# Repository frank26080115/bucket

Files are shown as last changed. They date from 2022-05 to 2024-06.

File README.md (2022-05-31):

Bucket
======

This is a tool made to transfer and backup photos from a professional camera while in-the-field. Built with a Raspberry Pi 4 (other Pis will work too, it's all just Python code), using Wi-Fi for file transfers and USB disks for file storage, powered by batteries.

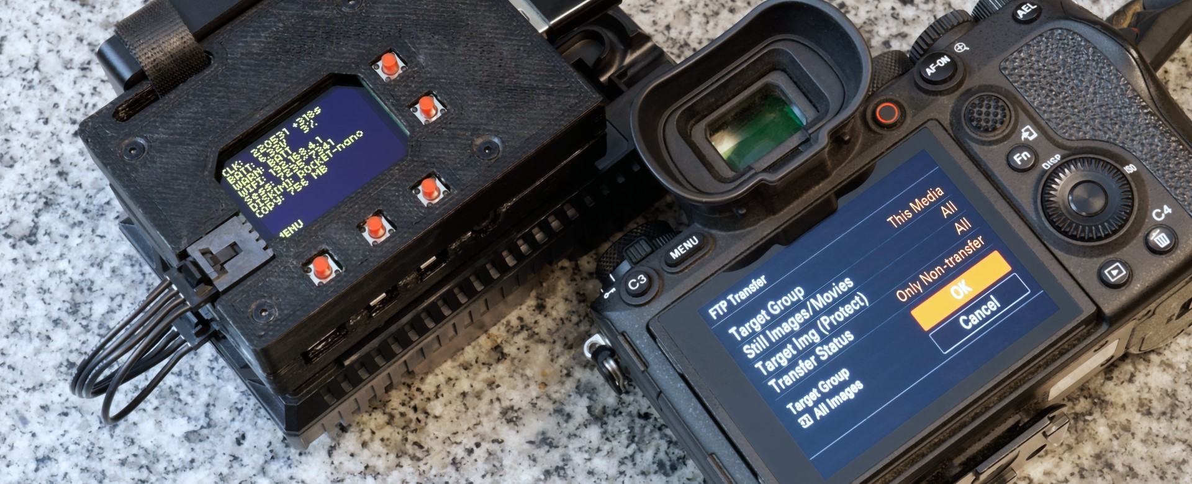
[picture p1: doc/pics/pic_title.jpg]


The Problem
----

 While on photography trips, I'm running out of storage on my camera's memory cards. They are expensive memory cards and I can't buy too many of them ($400 for 160 GB, and the camera needs two). I don't want to go back to a hotel before clearing out a memory card either.

So the strategy is to wirelessly transfer the files into a cheaper-slower-but-bigger storage device (TB sized USB disks) simultaneously as the camera is shooting. The slower speed should be fine because the transfers will happen during the down-time, when I'm walking around not taking pictures. USB disks at this size typically cost just a bit over $100 (genuine, authentic, non-scam ones) and require USB-3.0 ports.

Once the photos are in the bigger storage device, I can clear the expensive-and-smaller memory cards without going back to a hotel, using in-camera quick-reformat.

This project needs to be done by late June of 2022, my next vacation. (I hope this explains some very weird decisions I've made)

Features
----

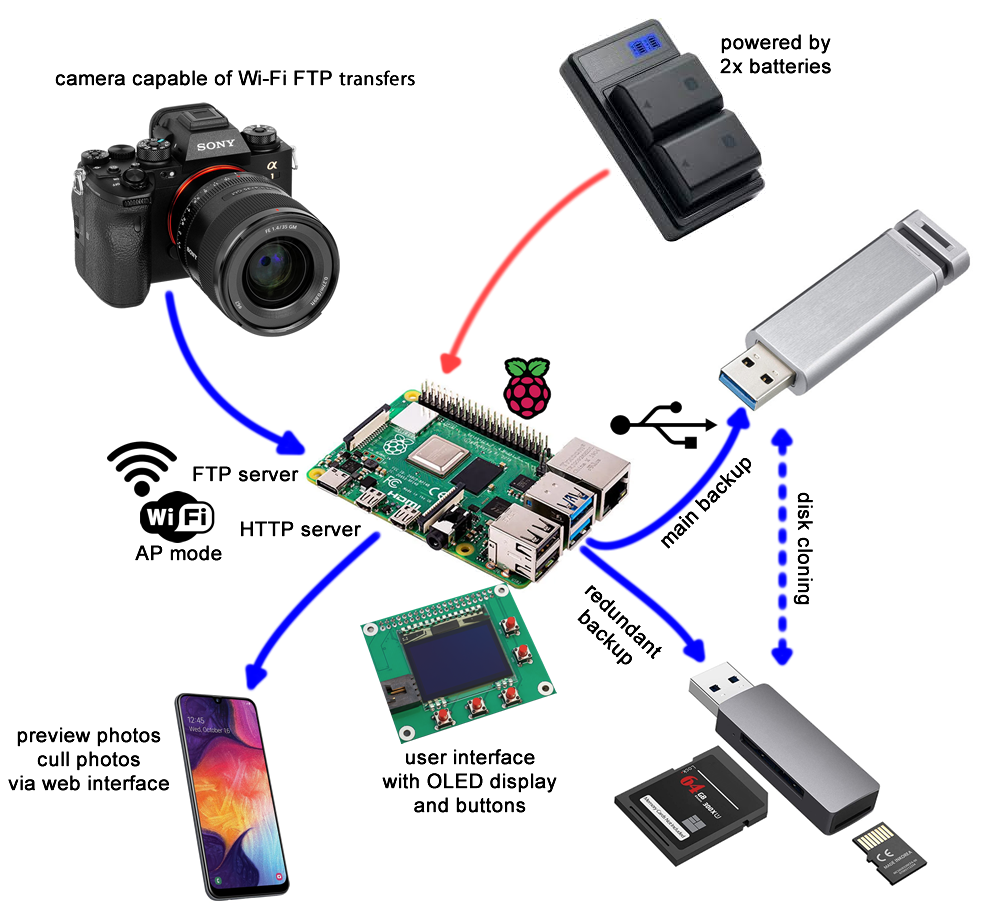
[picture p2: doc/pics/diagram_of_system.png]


Runs as a FTP server for professional cameras to transfer photos into. A redundant copy of the photo is made if 2 USB disks are inserted. (most professional cameras have two card slots for the purpose of having redundancy as well)

Copies photos from SD card if a SD card reader is inserted into a USB port. Or plug in the camera itself (configure it to run in mass storage mode, and disable USB charging).

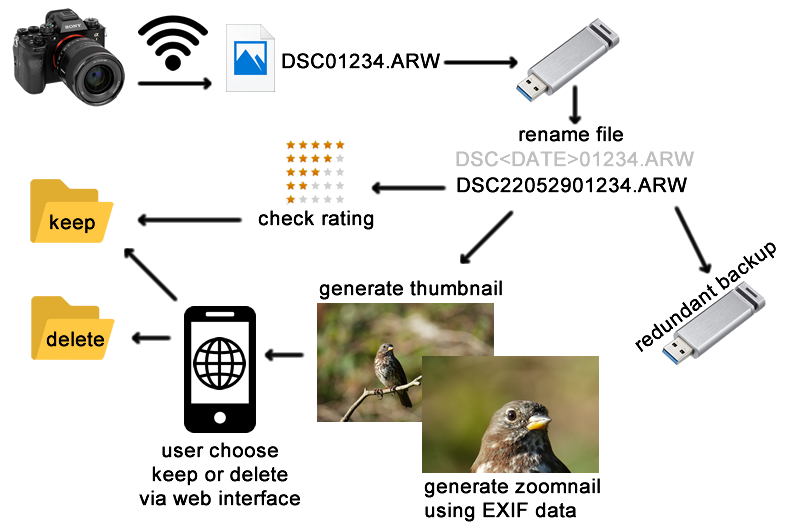
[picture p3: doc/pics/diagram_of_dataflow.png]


The file-names for the photos are typically numbered from 0 to 9999. This isn't a lot of photos and rolls over quickly. When a photo is copied, it is automatically renamed with a much longer number that indicates the date it was taken. The date makes every photo file-name unique and can be easily searched-for and sorted.

EXIF data of the photo is checked for the photo's 5-star rating, if it is rated in-camera, then it is automatically marked for keeping.

Performs disk-cloning when multiple USB disks are inserted.

Uses a HTTP server to show an image gallery in a web browser. The user can choose to keep or delete a photo from the web-page. Each photo is checked for where the camera focused on, and a zoomed-in cropped thumbnail is shown to the user showing where the camera focused (which is even cooler since my camera have AI driven bird-eye-detect).

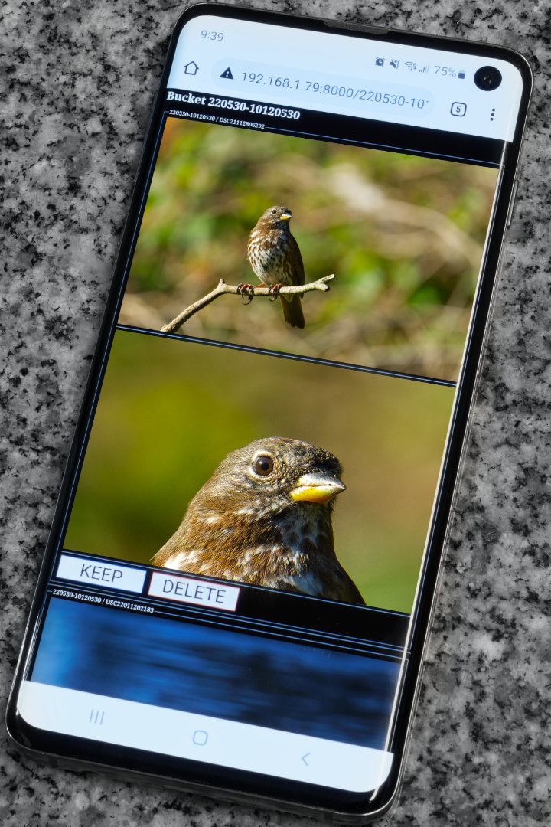
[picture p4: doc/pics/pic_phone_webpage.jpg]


This allows for a very quick decision whether or not an image is in-focus enough to keep. This implementation keeps the file-sizes small for the web-page, but the user can still click into the full resolution file too.

The software keeps track of the numbers in the file-names. If the number sequence skips a number, it might mean a missing photo, the missing number is shown to the user so they can check in the camera what happened. The camera can indicate a failed FTP transfer, but usually it just retries until it works. This is only useful when the camera is setup to transfer-as-you-shoot.

Hardware UX
----

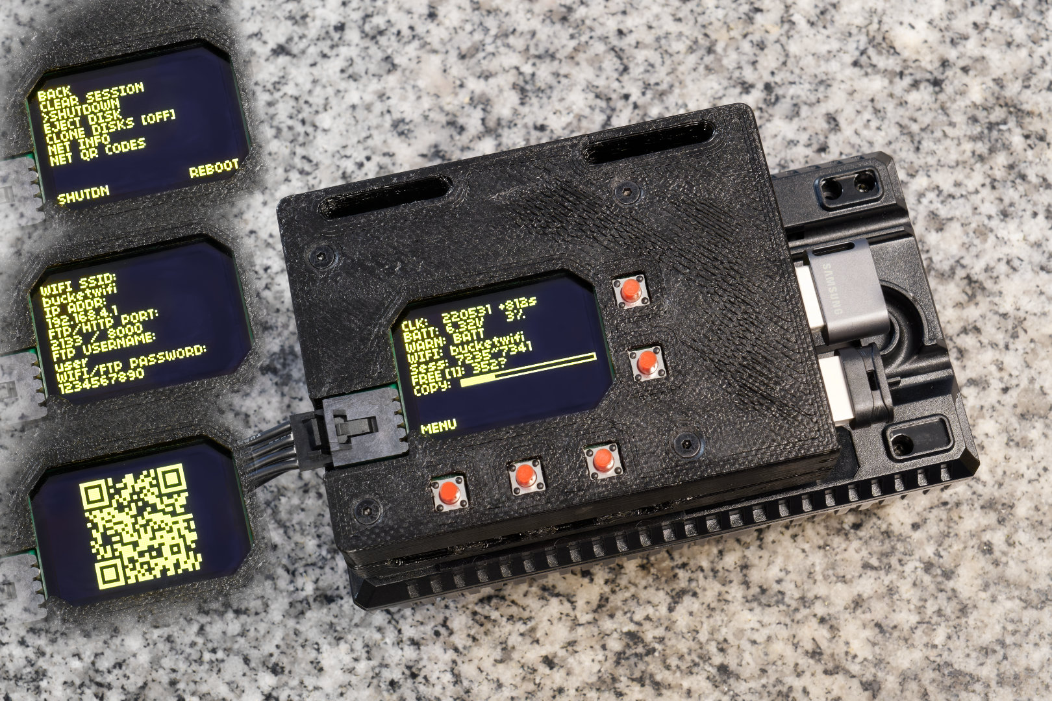
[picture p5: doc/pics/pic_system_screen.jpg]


The UI involves a 102x64 OLED screen and 5 buttons. It is very readable in all lighting conditions. The 5 buttons are divided into 2 up/down buttons and 3 action buttons.

The screen shows the most important information, such as the time (which is kind of like a heart-beat), the number of photos transferred, the amount of disk space remaining, etc.

There is a menu that can be accessed, the menu items are navigated with the up/down buttons. From the menu, the user can do things like initiate drive-cloning.

From the menu, the user can quickly check the Wi-Fi AP's credentials, the FTP IP address, and FTP credentials. It can also display the Wi-Fi credentials and HTTP URL as QR codes.

There is a buzzer that buzzes when there's a problem that requires the user's immediate attention, such as a disk running out of space, or if the battery is too low, etc. The user can press a button to acknowledge the problem to turn off the buzzer.

Hat Circuit and 3D Printed Box
----

This is the circuit I designed to go on top of the Raspberry Pi.

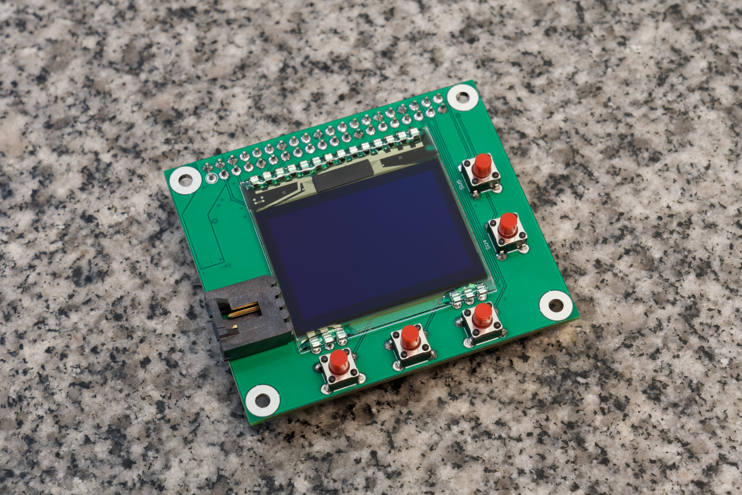
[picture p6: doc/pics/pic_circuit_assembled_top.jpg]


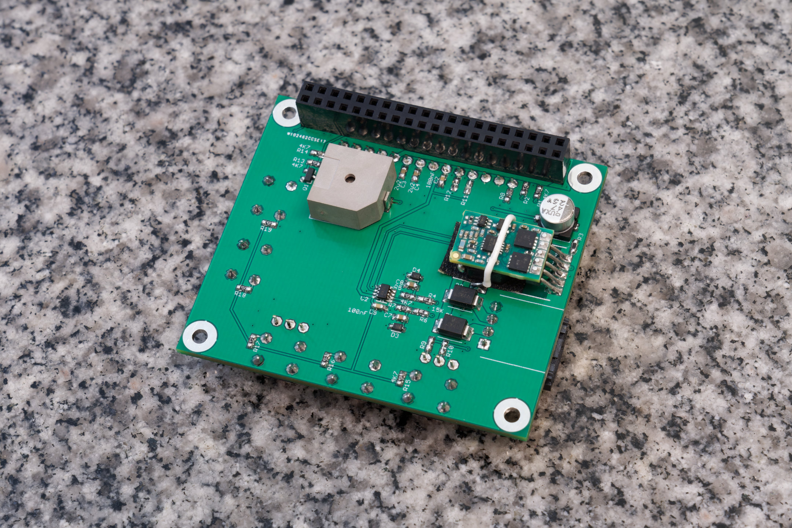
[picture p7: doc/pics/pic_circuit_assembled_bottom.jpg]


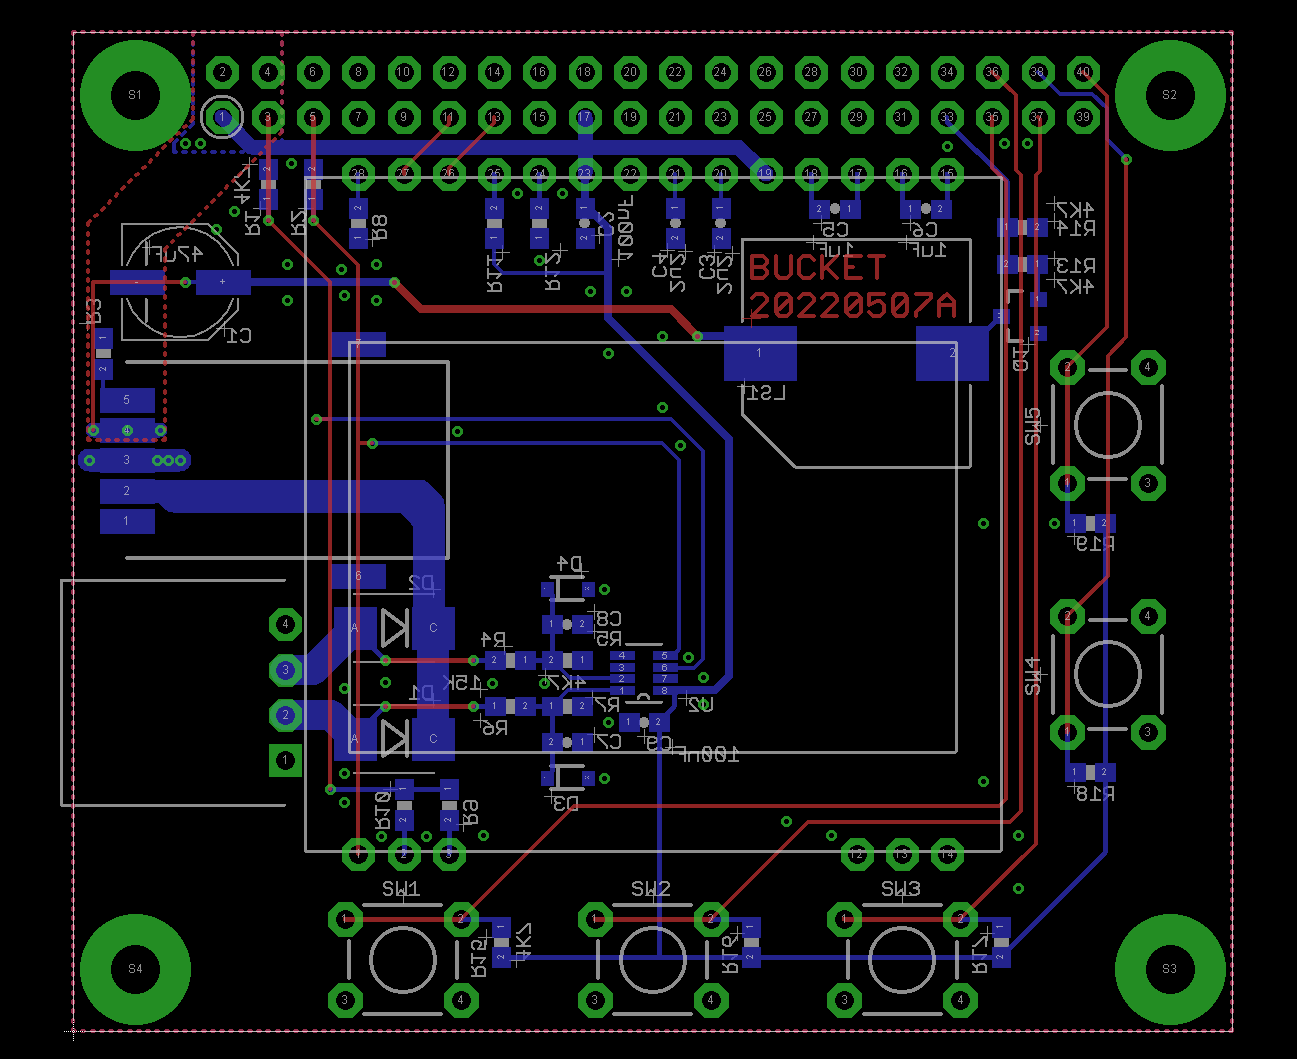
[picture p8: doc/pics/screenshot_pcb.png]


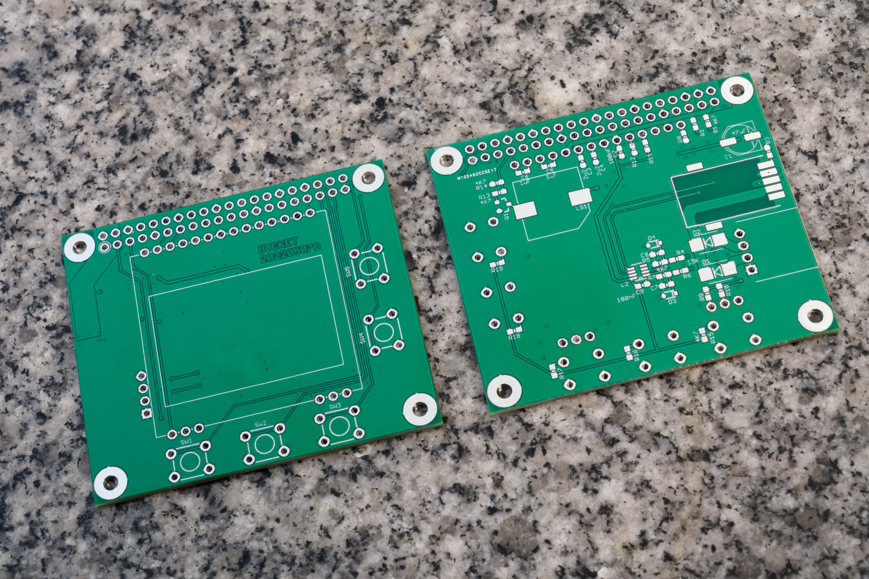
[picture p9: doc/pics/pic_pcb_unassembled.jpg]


A 3D printed box is designed to protect the entire assembly. It is 3D printed in PETG plastic, because this whole thing gets super hot while running, PLA plastic just won't handle it.

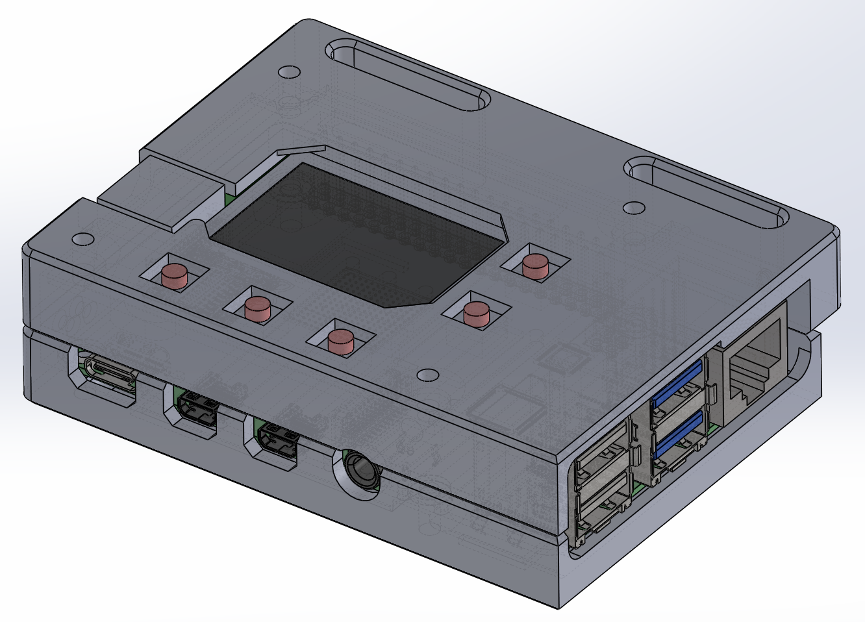
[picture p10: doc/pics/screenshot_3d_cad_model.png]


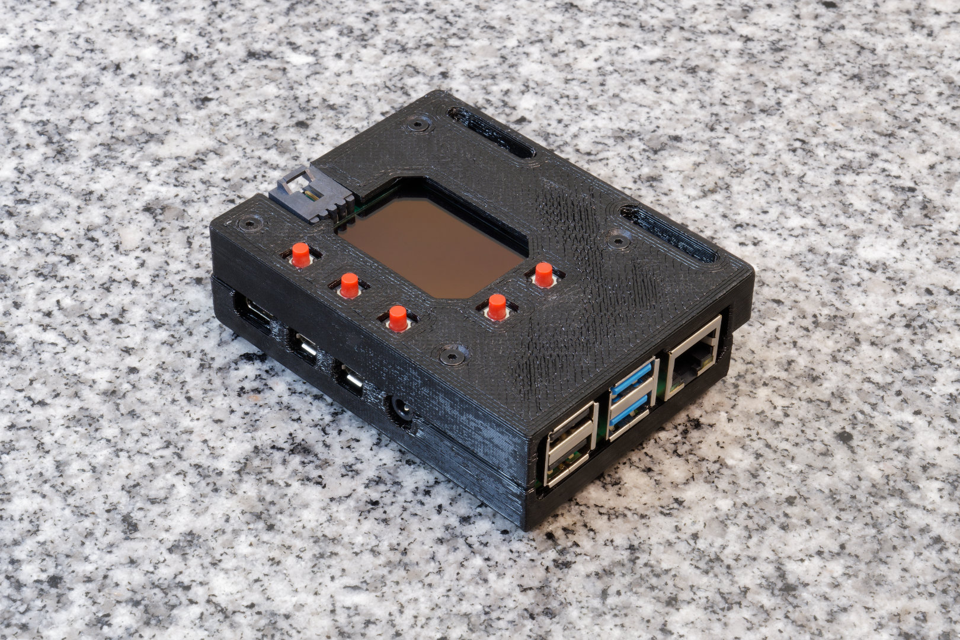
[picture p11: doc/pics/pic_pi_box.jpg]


The slots in the design are meant for strapping down a small USB SSD. These SSDs can have one or two TB of storage and should be pretty reliable since they use M.2 drives inside.

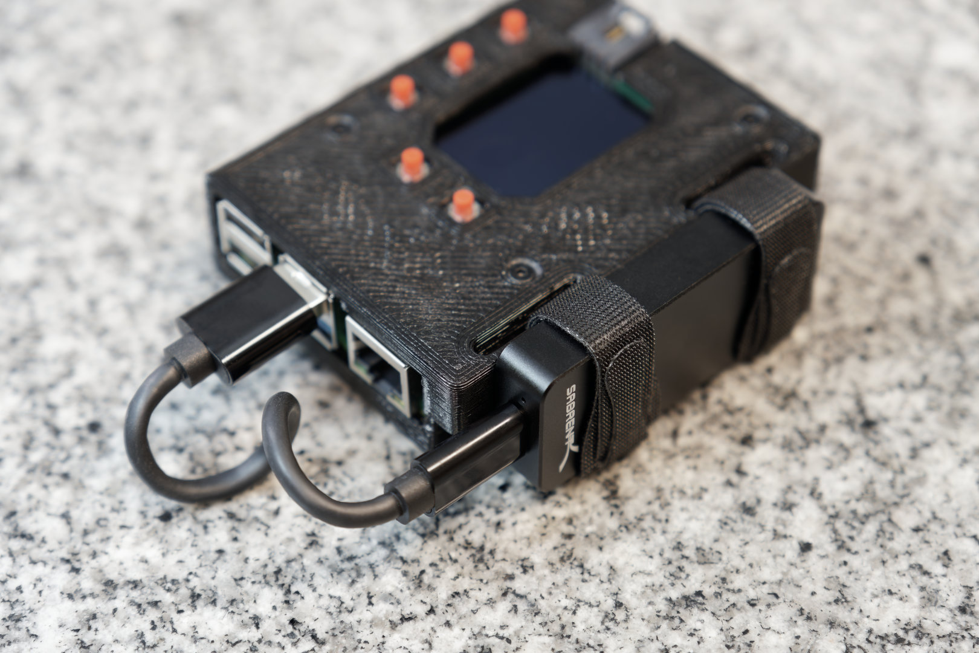
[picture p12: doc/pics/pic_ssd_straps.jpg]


Software Architecture
----

This is just one massive Python project, spread across several modules. The hardware IO, various servers, and the main application, can all be independently tested. In fact, because Python is very cross-platform, I did most of my testing on Windows with a simulated screen.

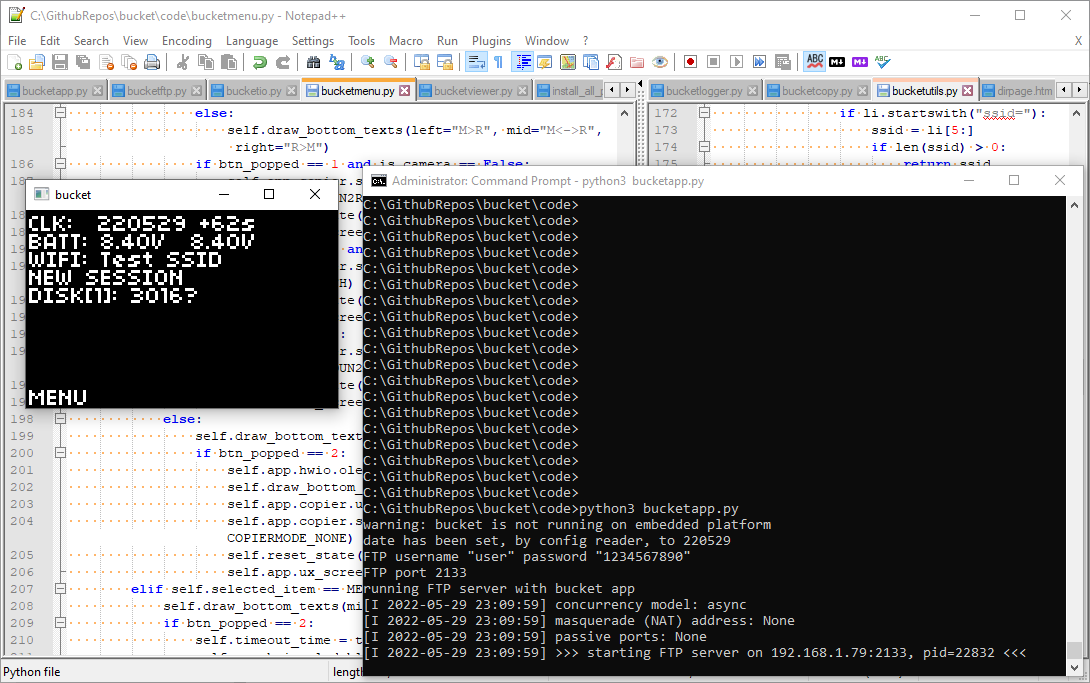
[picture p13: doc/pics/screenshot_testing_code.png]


The intention is to improve the reliability of this project by making the Raspberry Pi's microSD card read-only. The Python script will scan all mounted disks for a config file when it starts. This way, the user can still specify some parameters without ever writing to the microSD card.

The Python script will also log events and errors to the first available mounted disk.

The Python script is called upon by `/etc/rc.local`.

The library I used for the FTP server is [pyftpdlib](https://pypi.org/project/pyftpdlib/). The server class can be inherited, callback functions can be added, and a lot of the pathing functions had to be overridden.

The UI used a combination of [CircuitPython](https://circuitpython.org/) (and including the adafruit-circuitpython-ssd1306 library), [gpiozero](https://gpiozero.readthedocs.io/), and [Pillow](https://pillow.readthedocs.io/)

The HTTP server used Python's [built-in HTTP server library](https://docs.python.org/3/library/http.server.html). The HTML pages contains some [JQuery](https://jquery.com/) and uses lazy-loading images.

The EXIF related functions I borrowed [ExifTool](https://exiftool.org/), it's a Perl project but I call upon it as a subprocess from within Python.

USB disk auto-mounting is handled by [the usbmount Debian package](https://github.com/rbrito/usbmount/).

Threads
----

This device packs a bunch of features that involve IO against USB drives, and some of those tasks are more important. The software running has many threads that have multiple task queues with varying priorities.

The main thread is the GUI thread, which runs once every 0.2 seconds, giving a frame-rate of 5 FPS on the OLED display. Most of the thread time will be occupied by a very long I2C transaction as the frame-buffer is being sent to the OLED display. Other threads can run during this transfer without any penalty.

The FTP server and HTTP server both run on their own thread without any throttling, managed by their respective Python libraries. FTP is the most important thread. Wireless file transfer is the highest priority transfer, it isn't even queued, it happens immediately.

The other threads are started and stopped as needed: disk-cloner, keeper-copier, thumbnail-generator

The disk-cloner has two queues. The higher priority queue copies a recently wirelessly transferred file to the redundant disk. The lower priority queue copies between drives upon user request.

The keeper-copier slowly analyzes the EXIF data on recently transferred files to find their 5-star rating. Rated files are moved to the "keep" folder. These tasks has lower priority than the disk-cloner, but it also happens immediately if the user clicks the "keep" button on the HTTP server interface.

The thumbnail-generator thread is the lowest priority, but it becomes high priority when a HTTP client is accessing the thumbnails that have not been generating yet.

Power Supply
----

The hat circuit features a DC/DC step-down converter outputting 5V, rated for up to 6A. The input is supposed to come from two 8.4V batteries. The inputs are diode-OR'ed before going into the converter so I can swap one battery out without shutting down the Pi (and more importantly, prevents one battery literally exploding the other one). Each input is also connected to an ADC with a voltage divider in between.

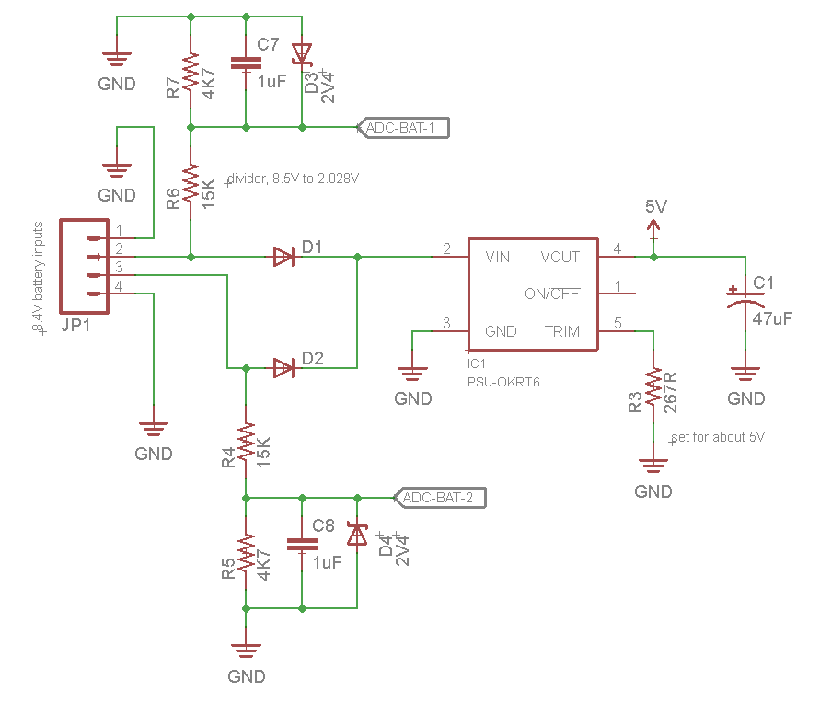
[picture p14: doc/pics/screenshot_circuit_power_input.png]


As for the batteries, I decided it would be smart to use the same FZ100 batteries that my cameras use, so I can carry less stuff. I hacked up a dual charger for FZ100 batteries so it became a battery holder. It will still charge the batteries too.

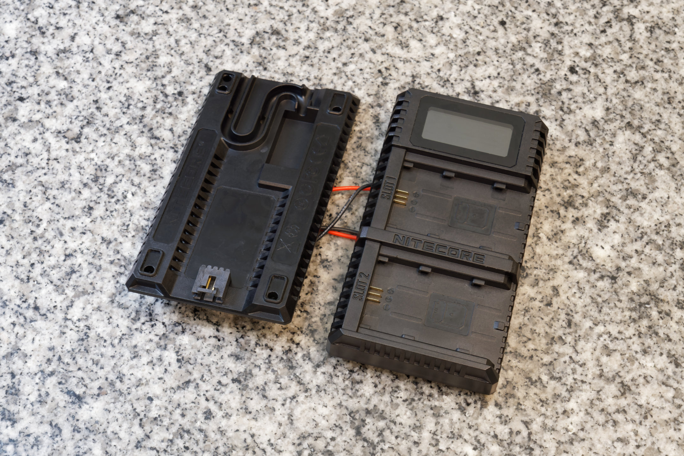
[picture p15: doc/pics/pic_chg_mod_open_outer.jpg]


A latching beefy connector is placed on the bottom of the charger, and wired to the battery tabs of the charger. On the Pi's hat is the mating connector.

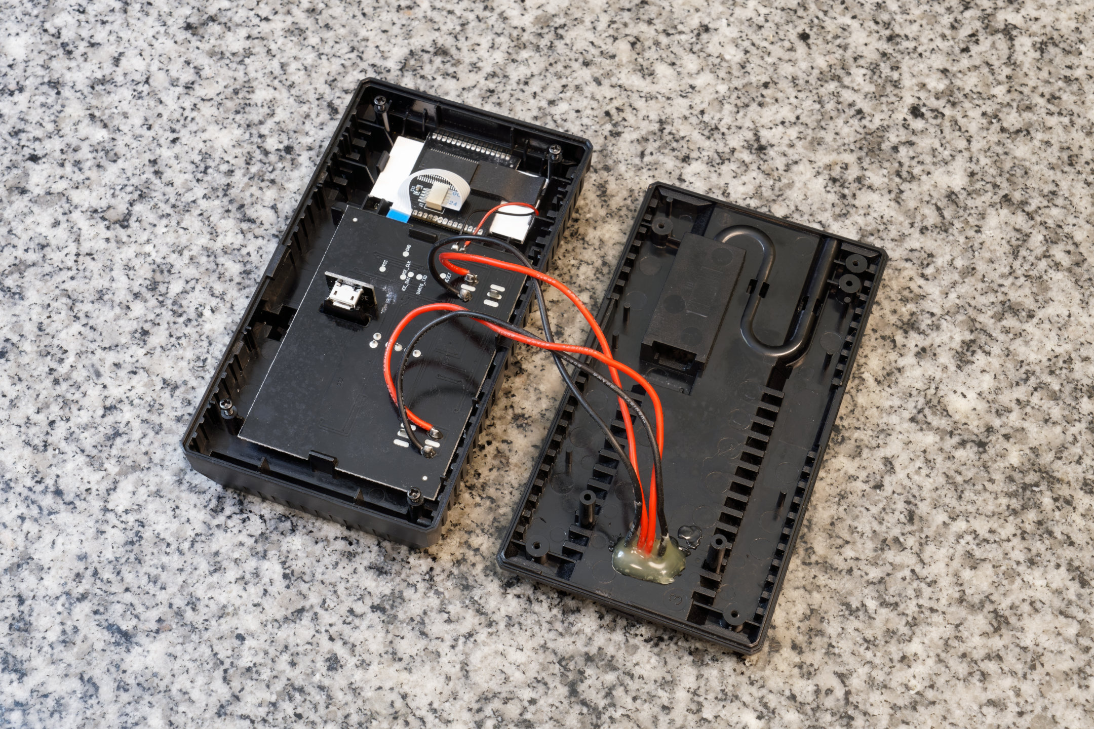
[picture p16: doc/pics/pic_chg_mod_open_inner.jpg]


This charger is attached to the bottom of the Raspberry Pi via LEGO!

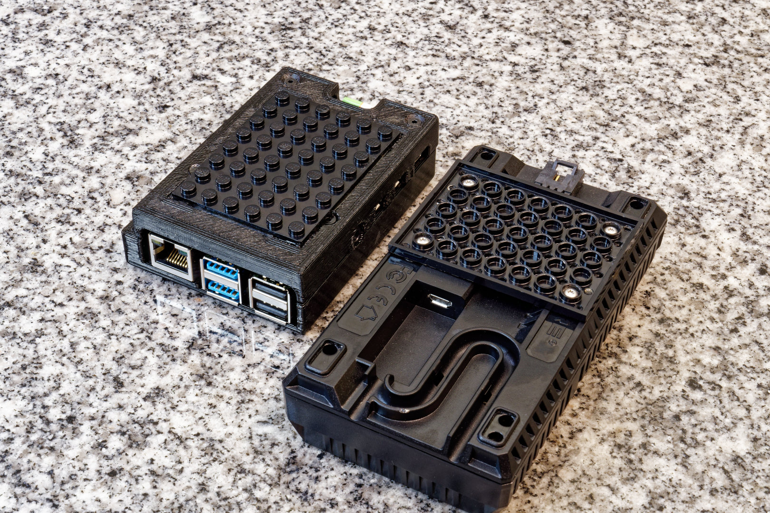
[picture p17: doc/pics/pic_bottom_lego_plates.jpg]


I think this whole project draws about under 1A during actual file transfer using USB flash drives, but a bit over 1A when I use a USB-C SSD. Roughly 4 to 5 hours of battery life.

Alternative Implementation
----

The Raspberry Pi 4 is absolutely horrible for a battery powered project, it has zero power saving features, there's no sleep mode, and draws a ton of current even if the whole CPU is halted. This whole project would've made a lot more sense if it was just a smartphone app.

But my phone doesn't have nearly enough internal storage for this project, the USB port on my phone is also very suspect and I don't want to have a USB hub inserted into it during hikes. I recently did a battery swap on my phone because I love it so much and want to use it for a few more years. So I hope you understand why I can't justify buying a 1 terabyte Galaxy S22 Ultra for this project.

I am interested in an Android app implementation of this device though. Contact me if you want to chat about it.

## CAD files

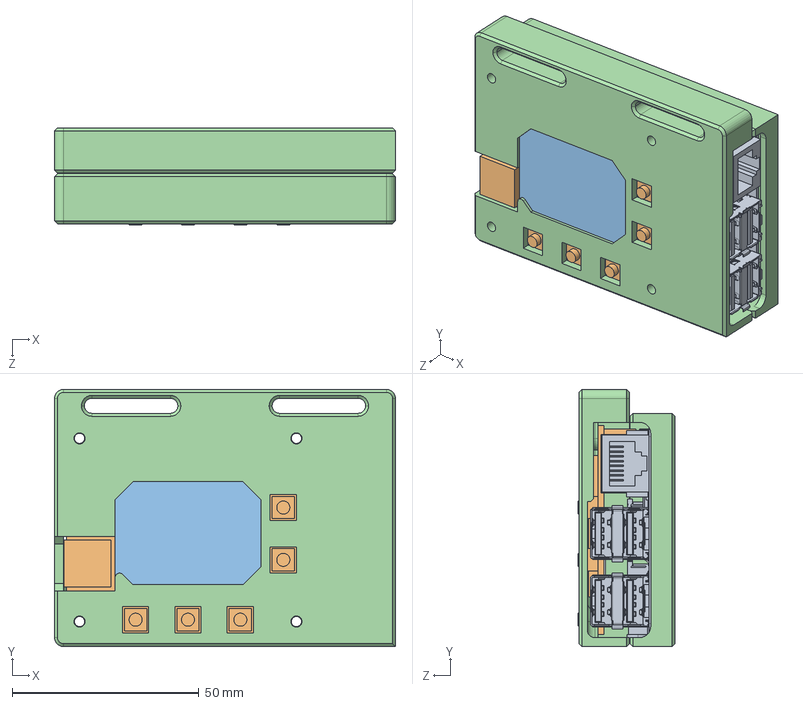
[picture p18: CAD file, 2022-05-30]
mech/assem.SLDASM
91.2 x 68.8 x 26.0 mm
Raspberry-Pi-4-Model-B-03
bucket_hat
pi_box

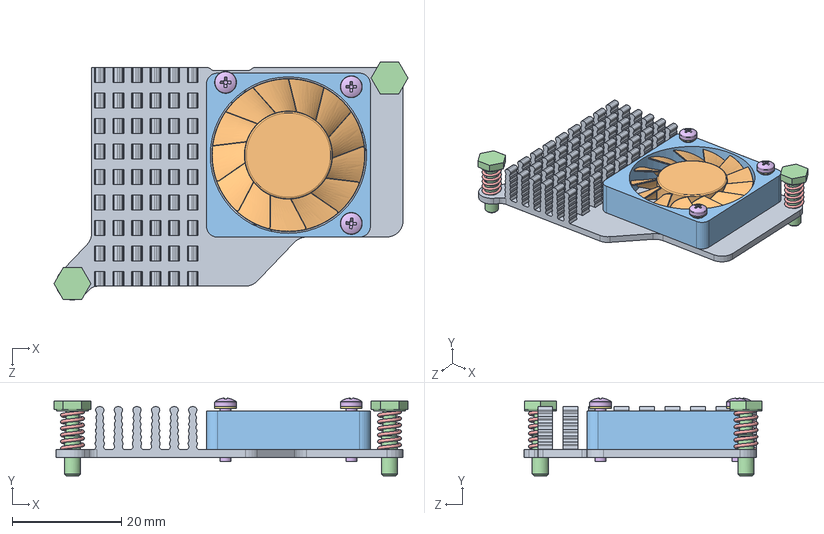
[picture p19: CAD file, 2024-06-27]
mech/rpi5/Heatsink+fan RPi-5.SLDASM
64.8 x 14.2 x 43.5 mm
Heatsink-fan-base_RPi5
RotorBlades
MotorHouse
Bolt_M3 PF x 2
Spring_M2,5 U x 2
pan head cross recess screw_din_DIN EN ISO 7045 - M2 x 10 - Z - 10N x 3
plain washer small grade a_din_Washer DIN 433 - 2 x 3

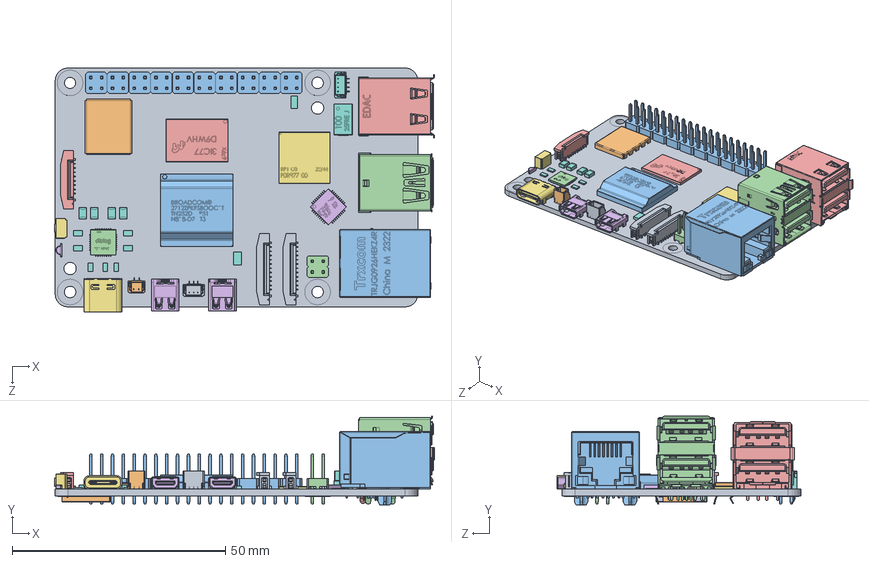
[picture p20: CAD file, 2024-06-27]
mech/rpi5/RASPBERRY_PI_5.SLDASM
89.0 x 20.8 x 57.2 mm
PLATE_RASPBERRY_PI_5
METAL_PLATE.
GIGABIT_ETHERNET_PORT
2xUSB_3.0_PORT
2xUSB_2.0_PORT
FEMALE_MICRO_HDMI_CONNECTOR x 2
FEMALE_USB_CONNECTOR
STOCK_1
STOCK_2
STOCK_3
3.0_PIN_HEADER_10
2.0_PIN_HEADER
9FD77_D9WHV
GIGABIT_ETHERNET_TRANSCEIVER
RP1_CO_CONTROLLER
CARD_SLOT_METAL_PIN
SD_CARD_V1
PART3_V1
BROADCOM_1
MxL
CAMERA_DISPLAY_1
BUTTON_MINI
BUTTON_2
CONNECT_V1
CAMERA_DISPLAY_2 x 2

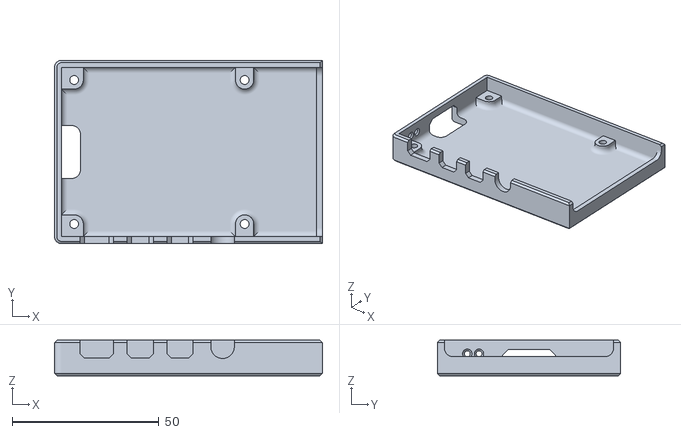
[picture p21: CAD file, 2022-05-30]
mech/pi_box_bottom.STL
91.2 x 62.4 x 12.1

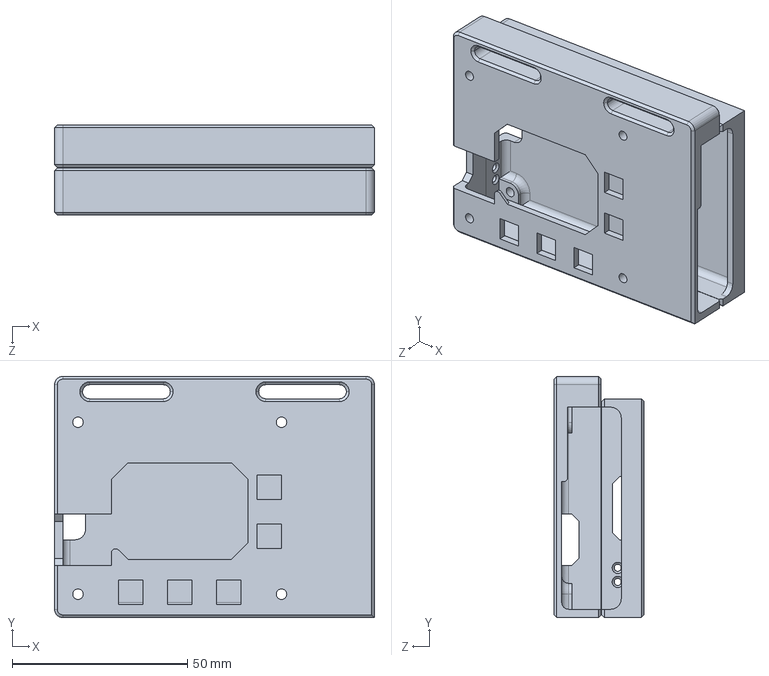
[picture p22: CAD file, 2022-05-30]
mech/pi_box.SLDPRT
91.2 x 68.8 x 25.7 mm

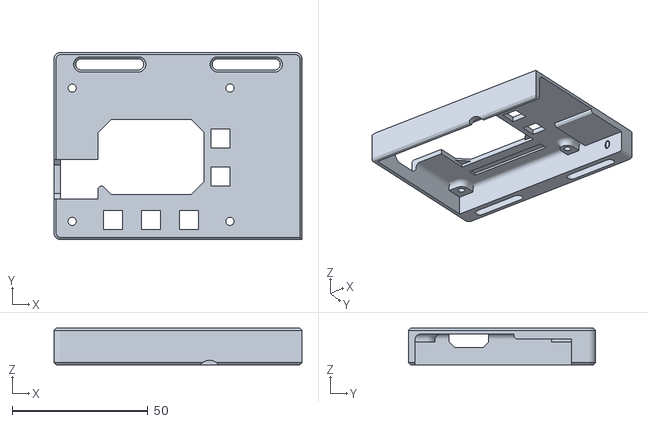
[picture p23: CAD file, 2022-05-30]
mech/pi_box_top_0.STL
91.2 x 68.8 x 13.5

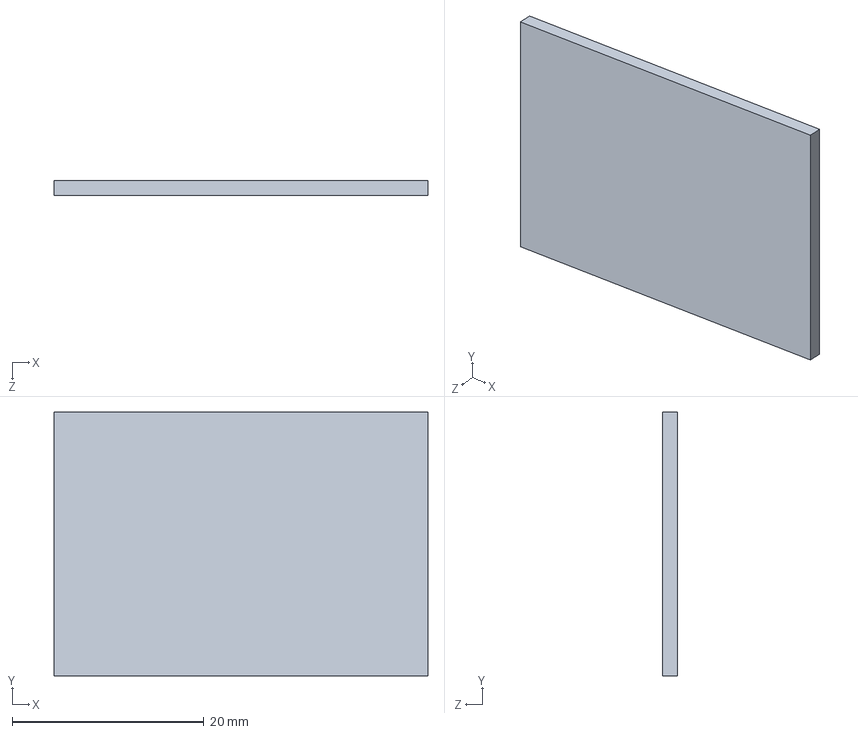
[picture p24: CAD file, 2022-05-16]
mech/screen_cover.SLDPRT
39.0 x 27.5 x 1.59 mm

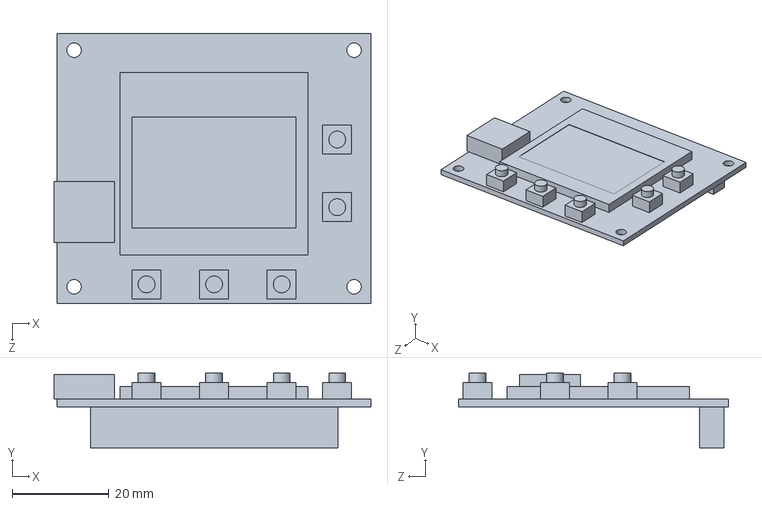
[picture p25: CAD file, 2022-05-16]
mech/bucket_hat.SLDPRT
65.7 x 15.5 x 56.0 mm

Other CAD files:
mech/rpi5/final_assembly.SLDASM
mech/rpi5/SLOT_CARD_ASM.SLDASM
mech/rpi5/CAMERA_DISPLAY_2.SLDPRT
mech/rpi5/CAMERA_DISPLAY_1.SLDPRT
mech/rpi5/2xUSB_2.0_PORT.SLDPRT
mech/rpi5/METAL_PLATE..SLDPRT
mech/rpi5/FEMALE_MICRO_HDMI_CONNECTOR.SLDPRT
mech/rpi5/fan cover.SLDPRT
mech/rpi5/CARD_SLOT_METAL_PIN.SLDPRT
mech/rpi5/RP1_CO_CONTROLLER.SLDPRT
mech/rpi5/2.0_PIN_HEADER.SLDPRT
mech/rpi5/2xUSB_3.0_PORT.SLDPRT
mech/rpi5/3.0_PIN_HEADER_10.SLDPRT
mech/rpi5/9FD77_D9WHV.SLDPRT
mech/rpi5/BROADCOM_1.SLDPRT
mech/rpi5/BUTTON_2.SLDPRT
mech/rpi5/BUTTON_MINI.SLDPRT
mech/rpi5/Bolt_M3 PF.SLDPRT
mech/rpi5/CONNECT_V1.SLDPRT
mech/rpi5/FEMALE_USB_CONNECTOR.SLDPRT
mech/rpi5/GIGABIT_ETHERNET_PORT.SLDPRT
mech/rpi5/GIGABIT_ETHERNET_TRANSCEIVER.SLDPRT
mech/rpi5/Heatsink-fan-base_RPi5.SLDPRT
mech/rpi5/MotorHouse.SLDPRT
mech/rpi5/MxL.SLDPRT
mech/rpi5/PART3_V1.SLDPRT
mech/rpi5/PLATE_RASPBERRY_PI_5.SLDPRT
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

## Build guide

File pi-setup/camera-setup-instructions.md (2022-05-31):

Camera Setup Instructions:

1. Enable Wi-Fi and connect to the access point SSID presented by the Raspberry Pi.

2. Enable the FTP Transfer function through the menu, the connection method should be Wi-Fi.

3. Configure a server, give it a name, and start editing the destination settings. The host-name field should contain the IP address of the Raspberry Pi, also set the correct port number. The secure protocol option should be OFF.

4. Edit the directory settings, the directory field should be left blank. The directory hierachy should be set to "same as in camera". The same-file-name rule should be set to "overwrite".

5. Put in the user credentials, which is shown by the Raspberry Pi.

6. Enable or disable automatic transfers as you desire.

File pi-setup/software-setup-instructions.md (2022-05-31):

Software Setup Instructions:

NOTE: I am not providing instructions for the hardware build online. These instructions are meant for individuals who have obtained hardware from me personally, or has the skills to build the hardware without my help.

1. Burn a microSD card with whatever is the latest Raspbian operating system, use a 64 bit headless version (Lite version). I am using Buster Lite.

2. Do the usual raspi-conf steps, such as setting the password, expand file-system, enable SSH and enable I2C. The next few steps depends on the Raspberry Pi being connected to your home network and the internet via ethernet. Do not use Wi-Fi.

3. SSH into the Pi.

4. Follow official instructions on setting up the Raspberry Pi as a Wi-Fi access point. The hostapd.conf file I used is provided as an example as well.

5. Execute the script I've included named `install_all_packages.sh`, if something goes wrong, handle the problem accordingly. I cannot anticipate the changes to the package repositories so I cannot automate the handling of these problems. If the script doesn't have execution flags set, then use `chmod` to set the `+x` flag for it.

6. Use git to clone this repo, `git clone https://github.com/frank26080115/bucket.git`.

7. Edit the files `/etc/rc.local` and `/etc/usbmount/usbmount.conf`, I've included examples in this git repo directory

8. Reboot, fool around, test, change my scripts if you need to. If you are happy with it then put the microSD card in read-only mode.

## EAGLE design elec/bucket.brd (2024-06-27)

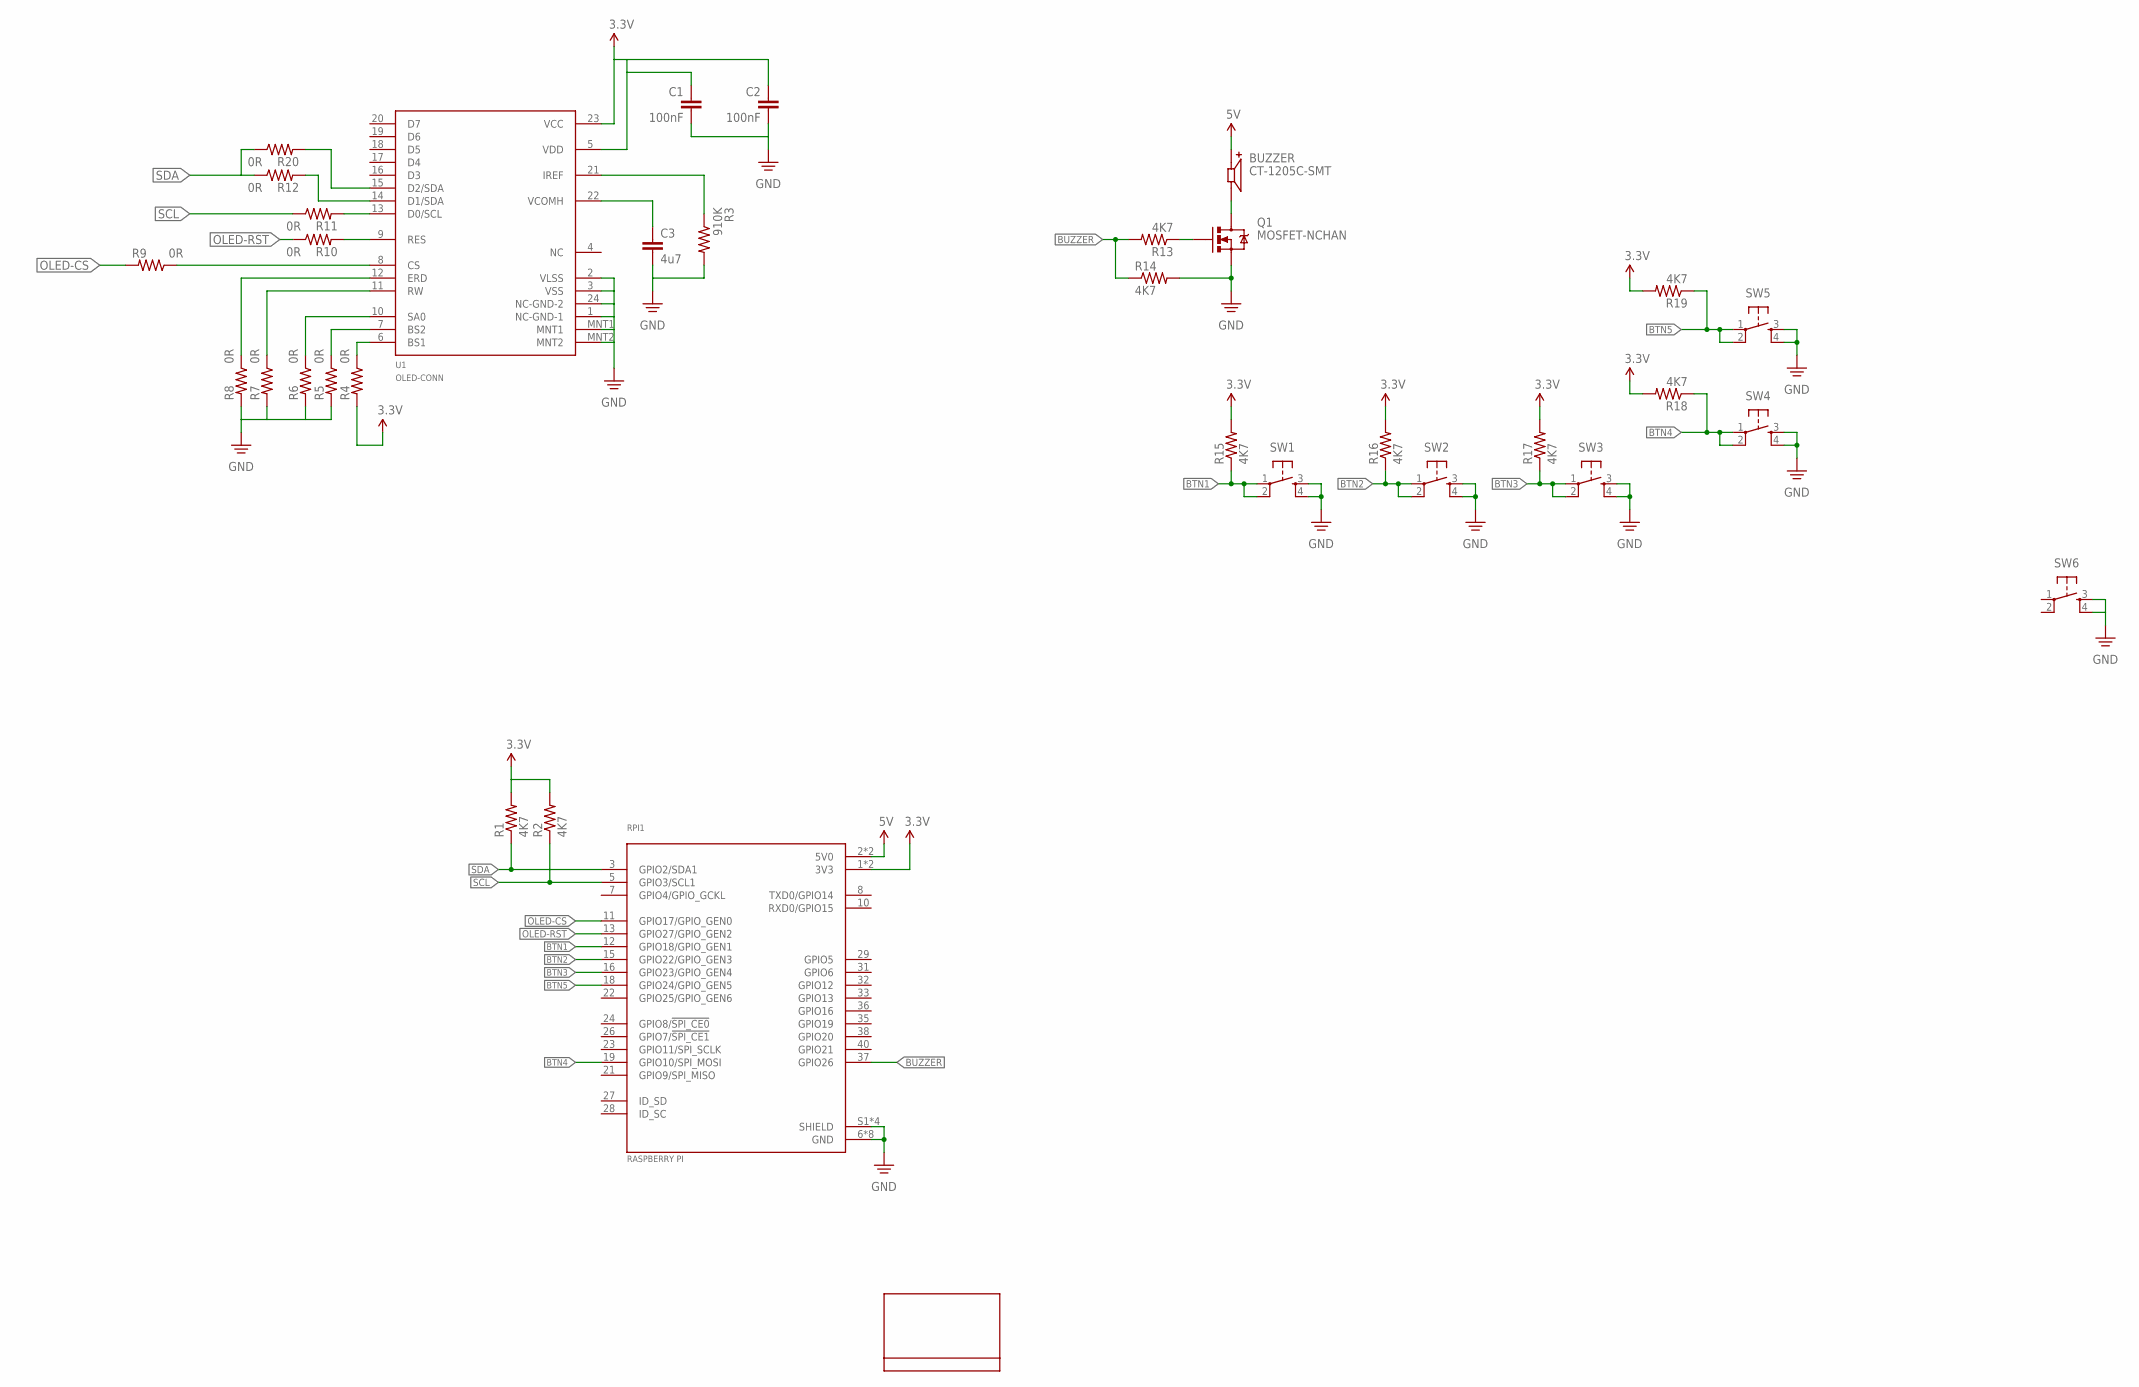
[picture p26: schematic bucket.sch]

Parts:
BUZZER: CT-1205C-SMT; CUI_CT-1205C-SMT
C1, C2: 100nF; 0603-CAP
C3: 4u7; 0603-CAP
Q1: MOSFET-NCHAN; SOT23-3
R1, R2, R13, R14, R15, R16, R17, R18, R19: 4K7; 0603-RES
R3: 910K; 0603-RES
R4, R5, R6, R7, R8, R9, R10, R11, R12, R20: 0R; 0603-RES
RPI1: RASPBERRY PI; MODULE_RASPBERRY_PI_3_MODEL_B+
SW1, SW2, SW3, SW4, SW5, SW6: TAC_SWITCHPTH; TACTILE-PTH
U1: OLED-CONN; CONN24_1X24_DRC_FFC_HIR
U$1: OLED-PANEL-1.54IN; OLED-1.54IN

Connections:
3.3V: C1.1, C2.1, R1.2, R2.2, R4.2, R15.2, R16.2, R17.2, R18.2, R19.2, RPI1.1 (3V3), RPI1.17 (3V3), U1.5 (VDD), U1.23 (VCC)
5V: BUZZER.1, RPI1.2 (5V0), RPI1.4 (5V0)
BTN1: R15.1, RPI1.12 (GPIO18/GPIO_GEN1), SW1.1, SW1.2
BTN2: R16.1, RPI1.15 (GPIO22/GPIO_GEN3), SW2.1, SW2.2
BTN3: R17.1, RPI1.16 (GPIO23/GPIO_GEN4), SW3.1, SW3.2
BTN4: R18.1, RPI1.19 (GPIO10/SPI_MOSI), SW4.1, SW4.2
BTN5: R19.1, RPI1.18 (GPIO24/GPIO_GEN5), SW5.1, SW5.2
BUZZER: R13.2, R14.1, RPI1.37 (GPIO26)
GND: C1.2, C2.2, C3.2, Q1.2 (S), R3.2, R5.2, R6.2, R7.2, R8.2, R14.2, RPI1.6 (GND), RPI1.9 (GND), RPI1.14 (GND), RPI1.20 (GND), RPI1.25 (GND), RPI1.30 (GND), RPI1.34 (GND), RPI1.39 (GND), RPI1.S1 (SHIELD), RPI1.S2 (SHIELD), RPI1.S3 (SHIELD), RPI1.S4 (SHIELD), SW1.3, SW1.4, SW2.3, SW2.4, SW3.3, SW3.4, SW4.3, SW4.4, SW5.3, SW5.4, SW6.3, SW6.4, U1.1 (NC-GND-1), U1.2 (VLSS), U1.3 (VSS), U1.24 (NC-GND-2), U1.MNT1, U1.MNT2
unnamed: C3.1, U1.22 (VCOMH)
unnamed: R3.1, U1.21 (IREF)
unnamed: R4.1, U1.6 (BS1)
unnamed: R5.1, U1.7 (BS2)
unnamed: Q1.1 (G), R13.1
unnamed: BUZZER.2, Q1.3 (D)
unnamed: R6.1, U1.10 (SA0)
unnamed: R7.1, U1.11 (RW)
unnamed: R8.1, U1.12 (ERD)
unnamed: R9.1, U1.8 (CS)
unnamed: R10.2, U1.9 (RES)
unnamed: R11.2, U1.13 (D0/SCL)
unnamed: R12.2, U1.14 (D1/SDA)
unnamed: R20.2, U1.15 (D2/SDA)
OLED-CS: R9.2, RPI1.11 (GPIO17/GPIO_GEN0)
OLED-RST: R10.1, RPI1.13 (GPIO27/GPIO_GEN2)
SCL: R2.1, R11.1, RPI1.5 (GPIO3/SCL1)
SDA: R1.1, R12.1, R20.1, RPI1.3 (GPIO2/SDA1)

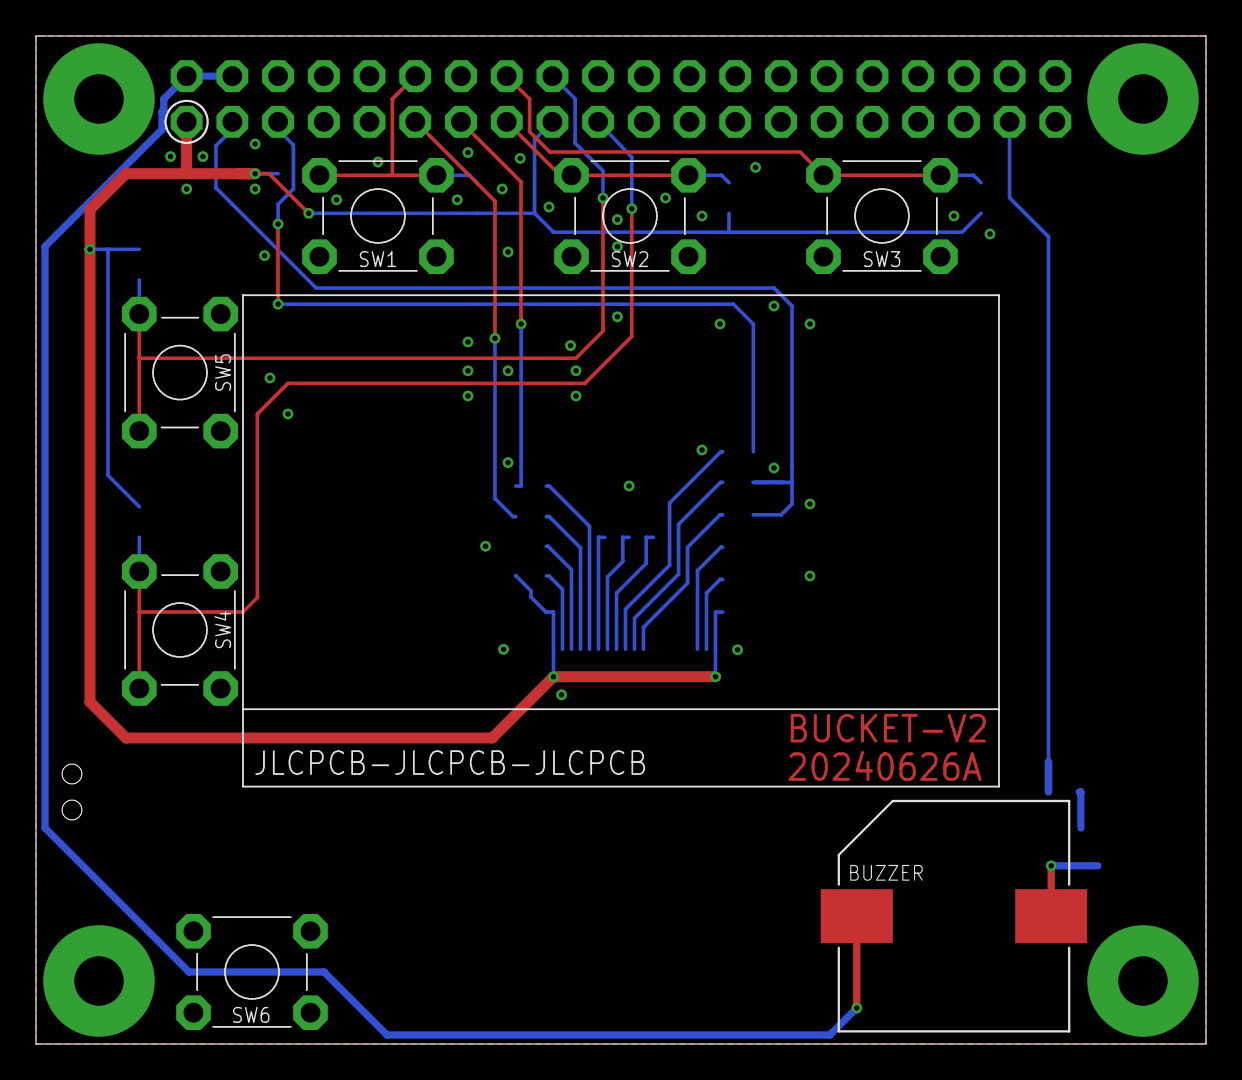
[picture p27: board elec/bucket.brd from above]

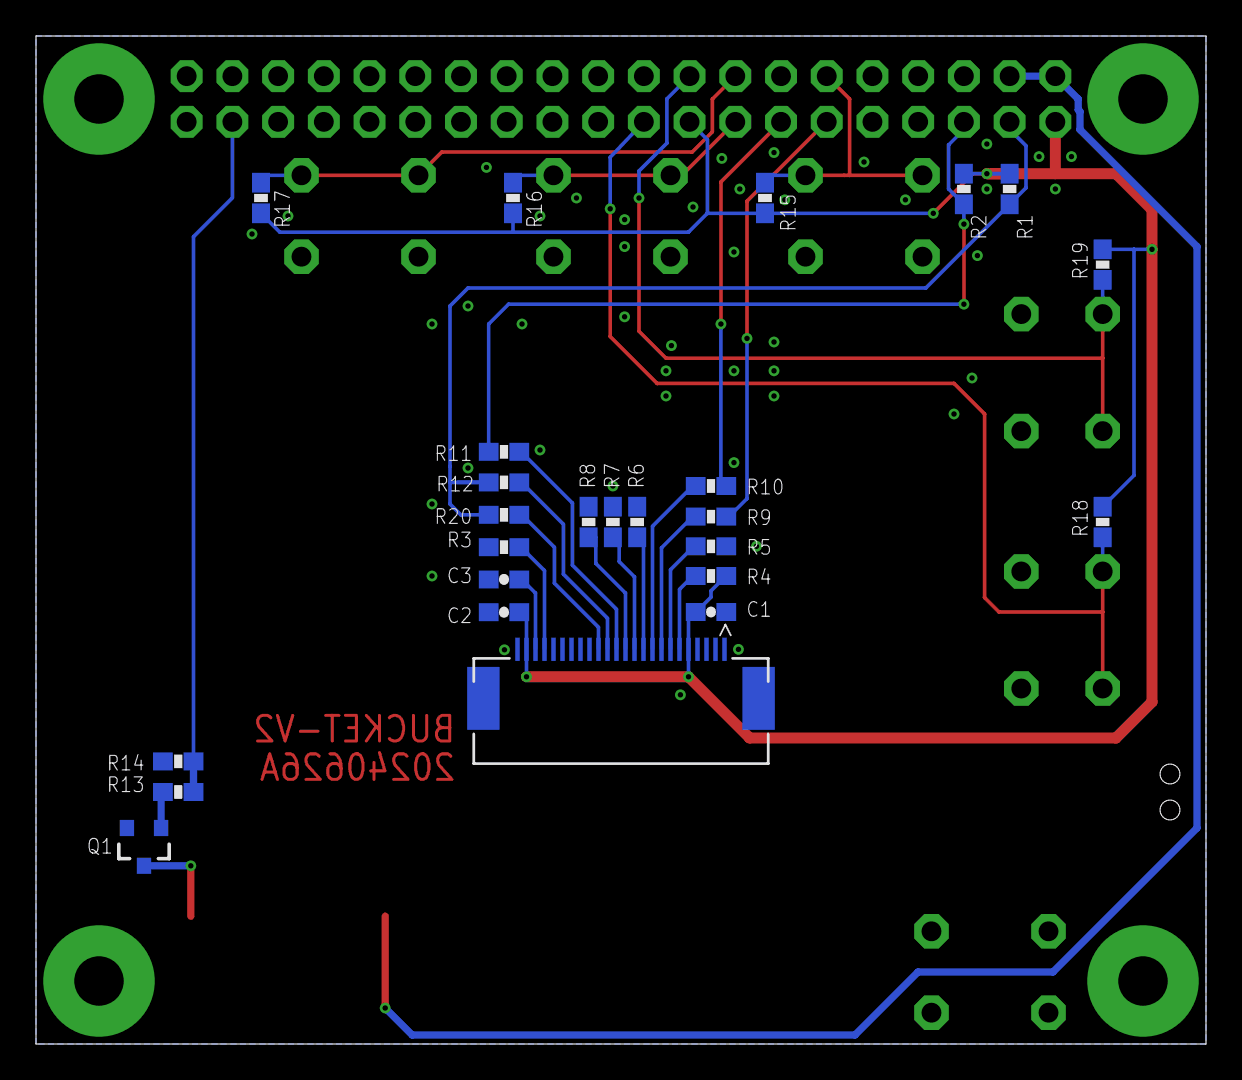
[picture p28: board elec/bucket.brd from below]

Board: 2 copper layers, 65.0 x 56.0 mm, 34 parts (25 on the bottom side), 27 nets.

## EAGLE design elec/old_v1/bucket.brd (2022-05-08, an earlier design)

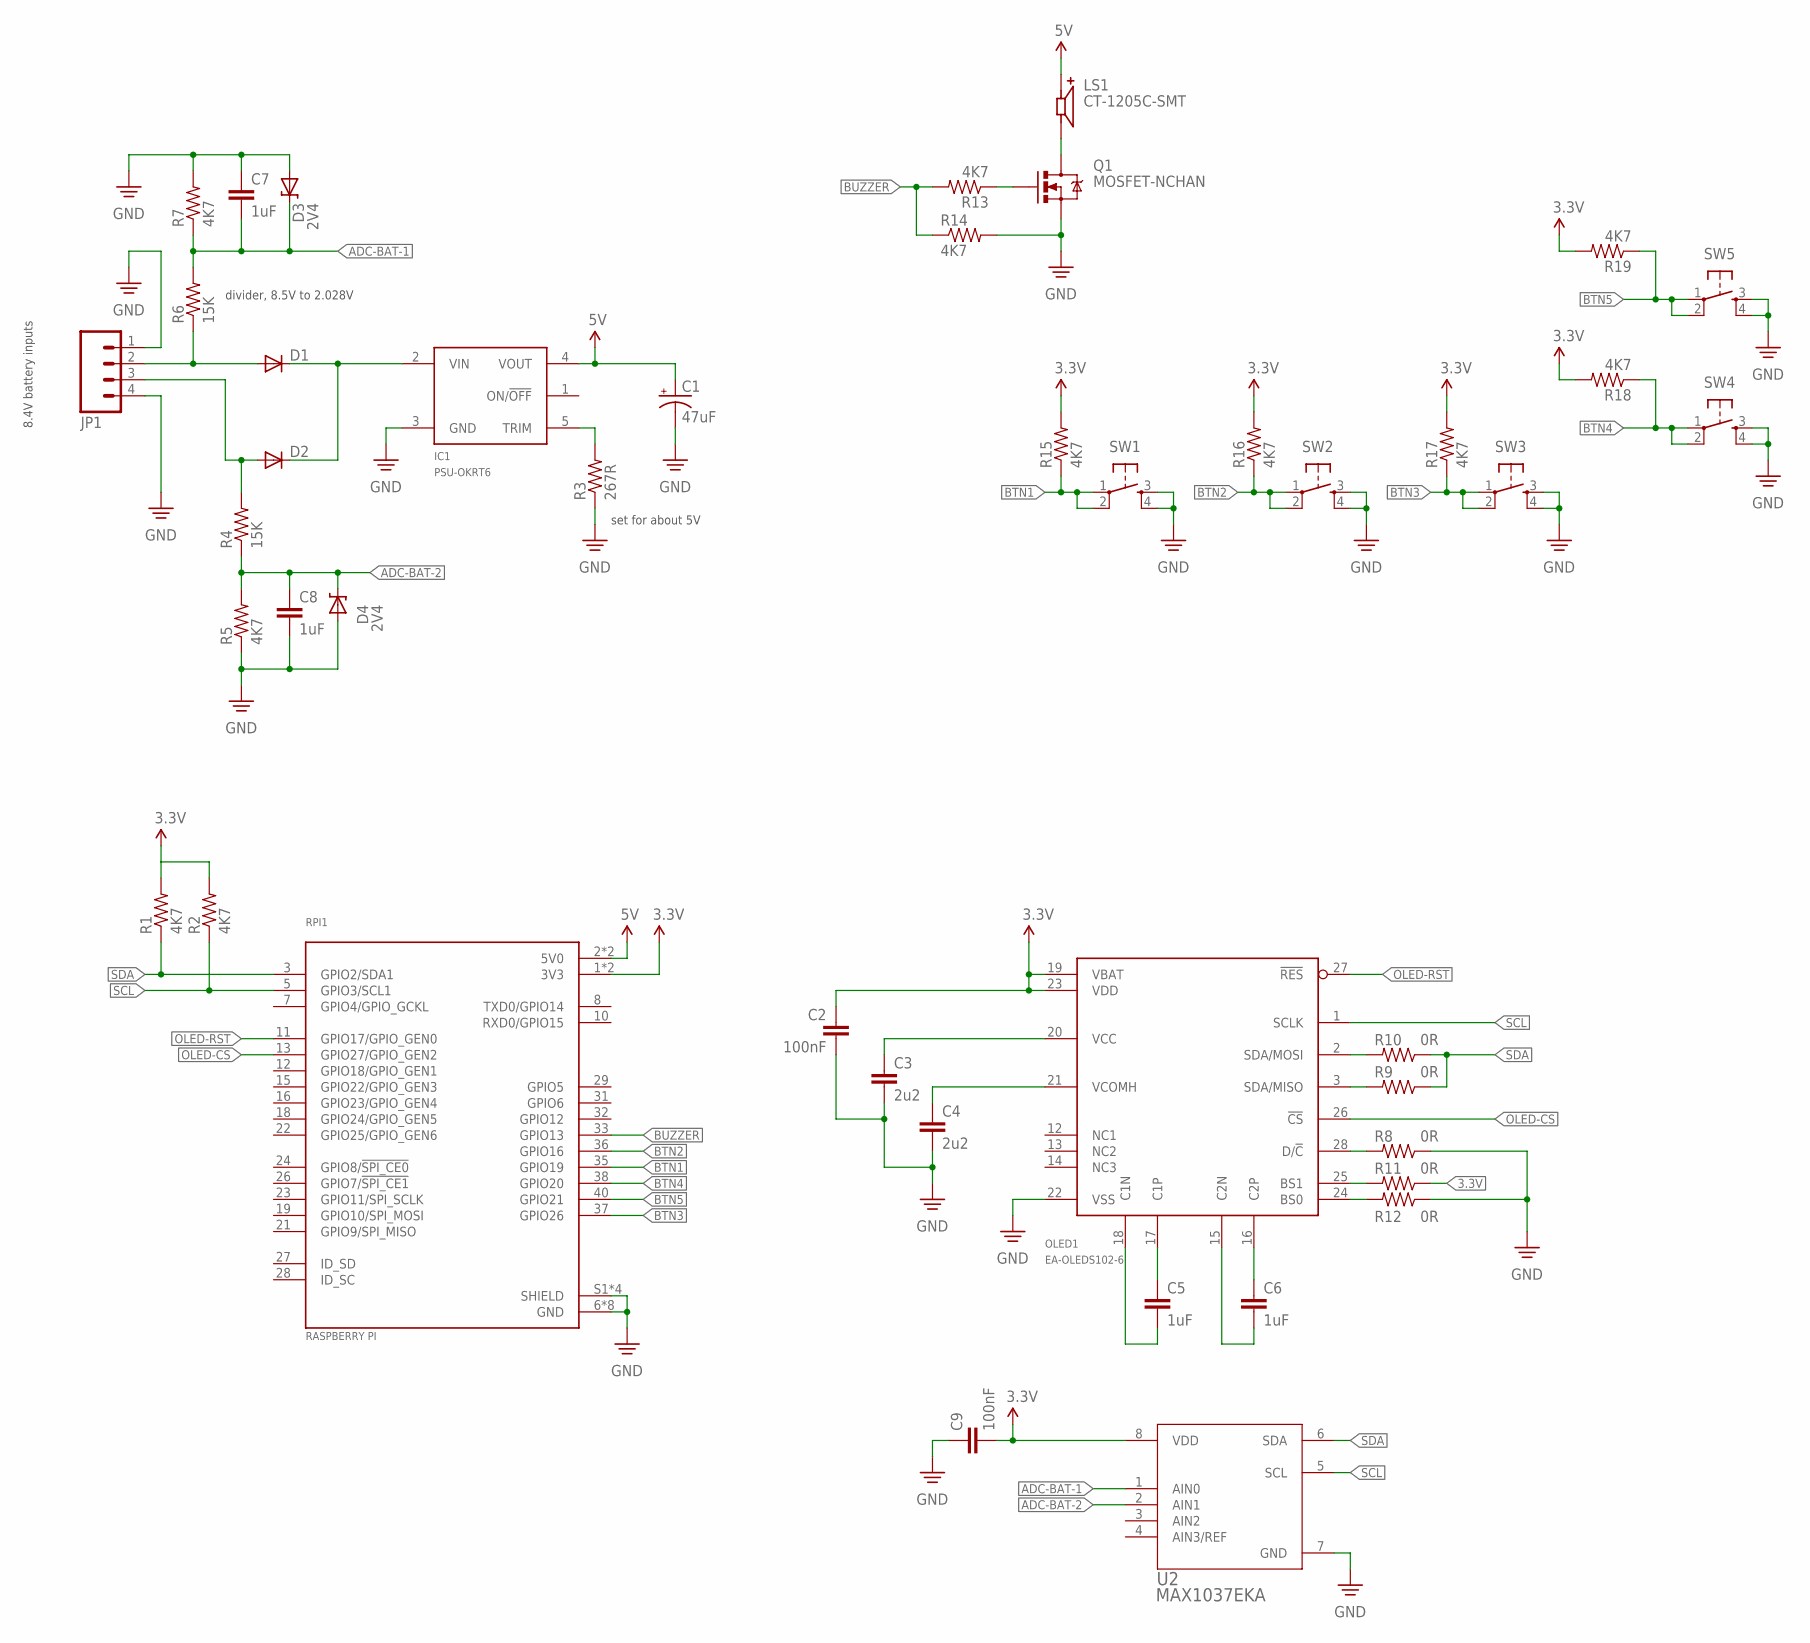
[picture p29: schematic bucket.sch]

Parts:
C1: 47uF; PANASONIC_D
C2, C9: 100nF; 0603-CAP
C3, C4: 2u2; 0603-CAP
C5, C6, C7, C8: 1uF; 0603-CAP
D1, D2: DIODESMB; SMB-DIODE
D3, D4: 2V4; SOD-323
IC1: PSU-OKRT6
JP1: M04-AMPMODUMTE-TH-ANG
LS1: CT-1205C-SMT; CUI_CT-1205C-SMT
OLED1: EA-OLEDS102-6
Q1: MOSFET-NCHAN; SOT23-3
R1, R2, R5, R7, R13, R14, R15, R16, R17, R18, R19: 4K7; 0603-RES
R3: 267R; 0603-RES
R4, R6: 15K; 0603-RES
R8, R9, R10, R11, R12: 0R; 0603-RES
RPI1: RASPBERRY PI; MODULE_RASPBERRY_PI_3_MODEL_B+
SW1, SW2, SW3, SW4, SW5: TAC_SWITCHPTH; TACTILE-PTH
U2: MAX1037EKA; 21-0078H

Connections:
3.3V: C2.1, C9.2, OLED1.19 (VBAT), OLED1.23 (VDD), R1.2, R2.2, R11.1, R15.2, R16.2, R17.2, R18.2, R19.2, RPI1.1 (3V3), RPI1.17 (3V3), U2.8 (VDD)
5V: C1.+, IC1.4 (VOUT), LS1.1, RPI1.2 (5V0), RPI1.4 (5V0)
ADC-BAT-1: C7.2, D3.1 (C), R6.2, R7.1, U2.1 (AIN0)
ADC-BAT-2: C8.1, D4.1 (C), R4.1, R5.2, U2.2 (AIN1)
BTN1: R15.1, RPI1.35 (GPIO19), SW1.1, SW1.2
BTN2: R16.1, RPI1.36 (GPIO16), SW2.1, SW2.2
BTN3: R17.1, RPI1.37 (GPIO26), SW3.1, SW3.2
BTN4: R18.1, RPI1.38 (GPIO20), SW4.1, SW4.2
BTN5: R19.1, RPI1.40 (GPIO21), SW5.1, SW5.2
BUZZER: R13.2, R14.1, RPI1.33 (GPIO13)
GND: C1.-, C2.2, C3.2, C4.2, C7.1, C8.2, C9.1, D3.2 (A), D4.2 (A), IC1.3 (GND), JP1.1, JP1.4, OLED1.22 (VSS), Q1.2 (S), R3.1, R5.1, R7.2, R8.1, R12.1, R14.2, RPI1.6 (GND), RPI1.9 (GND), RPI1.14 (GND), RPI1.20 (GND), RPI1.25 (GND), RPI1.30 (GND), RPI1.34 (GND), RPI1.39 (GND), RPI1.S1 (SHIELD), RPI1.S2 (SHIELD), RPI1.S3 (SHIELD), RPI1.S4 (SHIELD), SW1.3, SW1.4, SW2.3, SW2.4, SW3.3, SW3.4, SW4.3, SW4.4, SW5.3, SW5.4, U2.7 (GND)
unnamed: D2.A, JP1.3, R4.2
unnamed: D1.A, JP1.2, R6.1
unnamed: D1.C, D2.C, IC1.2 (VIN)
unnamed: IC1.5 (TRIM), R3.2
unnamed: Q1.1 (G), R13.1
unnamed: LS1.2, Q1.3 (D)
unnamed: OLED1.28 (D/!C), R8.2
unnamed: OLED1.3 (SDA/MISO), R9.2
unnamed: OLED1.2 (SDA/MOSI), R10.2
unnamed: OLED1.25 (BS1), R11.2
unnamed: OLED1.24 (BS0), R12.2
unnamed: C4.1, OLED1.21 (VCOMH)
unnamed: C3.1, OLED1.20 (VCC)
unnamed: C5.2, OLED1.18 (C1N)
unnamed: C5.1, OLED1.17 (C1P)
unnamed: C6.1, OLED1.16 (C2P)
unnamed: C6.2, OLED1.15 (C2N)
OLED-CS: OLED1.26 (!CS), RPI1.13 (GPIO27/GPIO_GEN2)
OLED-RST: OLED1.27 (!RES), RPI1.11 (GPIO17/GPIO_GEN0)
SCL: OLED1.1 (SCLK), R2.1, RPI1.5 (GPIO3/SCL1), U2.5 (SCL)
SDA: R1.1, R9.1, R10.1, RPI1.3 (GPIO2/SDA1), U2.6 (SDA)

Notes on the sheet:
set for about 5V
8.4V battery inputs
divider, 8.5V to 2.028V

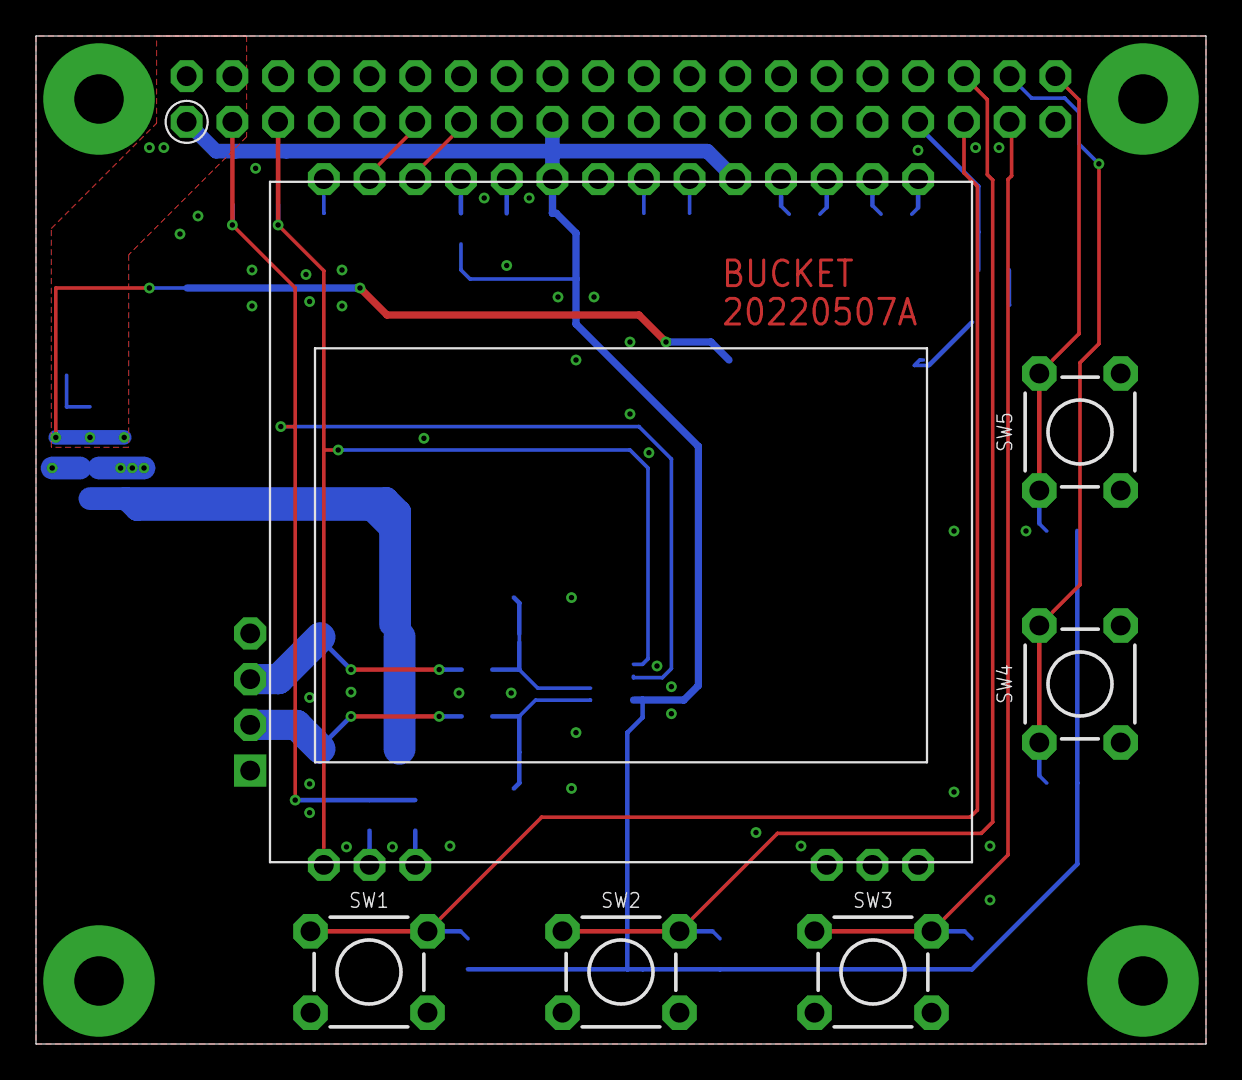
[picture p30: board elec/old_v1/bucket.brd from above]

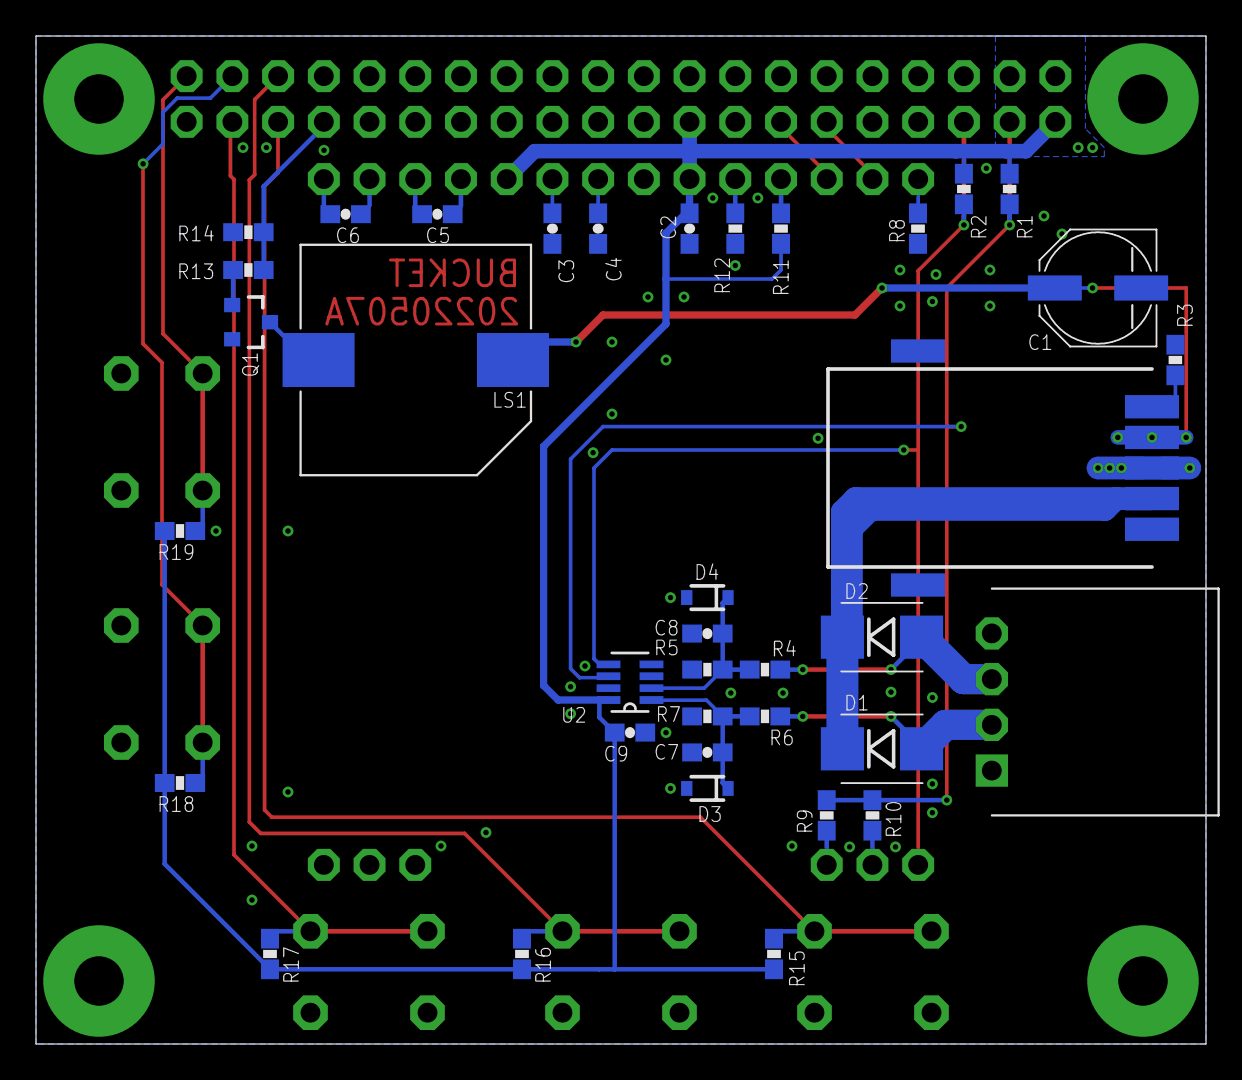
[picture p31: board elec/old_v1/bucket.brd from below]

Board: 2 copper layers, 65.0 x 56.0 mm, 44 parts (37 on the bottom side), 32 nets.

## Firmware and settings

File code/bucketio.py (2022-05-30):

#!/usr/bin/env python3

import sys, os, time, queue, glob

is_embedded = True

try:
    import board, busio
    import RPi.GPIO as GPIO
    import gpiozero
    import adafruit_ssd1306
except:
    print("warning: bucket is not running on embedded platform")
    is_embedded = False
    import cv2, numpy

from PIL import Image, ImageDraw, ImageFont

try:
    import bucketlogger
    logger = bucketlogger.getLogger()
except:
    pass

PIN_OLED_RESET = 17
PIN_OLED_CS    = 27
PIN_BUZZER     = 13
PIN_BTN_1      = 19
PIN_BTN_2      = 16
PIN_BTN_3      = 26
PIN_BTN_4      = 20
PIN_BTN_5      = 21

PIN_PULLUP_CONFIG = None
BUTTON_DEBOUNCE   = 0.01

BATT_VDIV_RLOWER      = 4.7  # resistor value of voltage divider
BATT_VDIV_RUPPER      = 15.0 # resistor value of voltage divider
BATT_VOLT_COMPENSATE  = 0.0  # there are diodes that will drop the voltage a bit
BATT_ADC_INTERNAL_REF = 2.048
BATT_VOLT_CALIBRATION_SCALE_M = 2.7027
BATT_VOLT_CALIBRATION_SCALE_B = -8.10811

OLED_WIDTH  = 102
OLED_HEIGHT = 64

I2CADDR_OLED = (0x78 >> 1)
I2CADDR_ADC  = (0xC8 >> 1)

class BucketIO:

    def __init__(self):
        self.is_sim = False
        self.buzzer_is_on = 0
        self.batt_raw  = [-1, -1]
        self.batt_volt = [-1, -1]
        self.batt_chg  = [-100, -100]
        self.button_queue = queue.Queue()
        self.adc_avail = False

    def hw_init(self):
        self.init_pins()
        self.init_buttons()
        self.init_adc()
        self.init_oled()
        self.oled_blankimage()

    def init_pins(self):
        self.i2c           = busio.I2C(board.SCL, board.SDA)
        self.pin_oledreset = gpiozero.DigitalOutputDevice(PIN_OLED_RESET, initial_value=False)
        self.pin_oledcs    = gpiozero.DigitalOutputDevice(PIN_OLED_CS   , initial_value=False)
        self.buzzer        = gpiozero.DigitalOutputDevice(PIN_BUZZER    , initial_value=False)

    def init_buttons(self):
        self.button_1 = gpiozero.Button(PIN_BTN_1, active_state = False, pull_up = PIN_PULLUP_CONFIG, bounce_time = BUTTON_DEBOUNCE)
        self.button_2 = gpiozero.Button(PIN_BTN_2, active_state = False, pull_up = PIN_PULLUP_CONFIG, bounce_time = BUTTON_DEBOUNCE)
        self.button_3 = gpiozero.Button(PIN_BTN_3, active_state = False, pull_up = PIN_PULLUP_CONFIG, bounce_time = BUTTON_DEBOUNCE)
        self.button_4 = gpiozero.Button(PIN_BTN_4, active_state = False, pull_up = PIN_PULLUP_CONFIG, bounce_time = BUTTON_DEBOUNCE)
        self.button_5 = gpiozero.Button(PIN_BTN_5, active_state = False, pull_up = PIN_PULLUP_CONFIG, bounce_time = BUTTON_DEBOUNCE)
        self.buttons = [self.button_1, self.button_2, self.button_3, self.button_4, self.button_5]
        self.button_1.when_pressed = self.on_pressed_1
        self.button_2.when_pressed = self.on_pressed_2
        self.button_3.when_pressed = self.on_pressed_3
        self.button_4.when_pressed = self.on_pressed_4
        self.button_5.when_pressed = self.on_pressed_5
        #self.button_4.when_held    = self.on_pressed_4
        #self.button_5.when_held    = self.on_pressed_5
        #self.button_4.hold_time    = 0.5
        #self.button_5.hold_time    = 0.5
        #self.button_4.hold_repeat  = True
        #self.button_5.hold_repeat  = True
        # note: gpiozero's button-hold detection is incredibly unreliable, do not use

    def init_oled(self, reinit = False):
        self.image = Image.new("1", (OLED_WIDTH, OLED_HEIGHT))
        self.imagedraw = ImageDraw.Draw(self.image)
        time.sleep(0.01)
        self.pin_oledreset.on()
        time.sleep(0.01)
        self.disp = adafruit_ssd1306.SSD1306_I2C(OLED_WIDTH, OLED_HEIGHT, self.i2c, addr = I2CADDR_OLED, external_vcc = False)
        self.disp.rotate(False) # this is required or else it's flipped by default
        if reinit == False:
            # testing shows that the initialization from the datasheet is worse
            # just stick with the Adafruit code
            return
        self.pin_oledreset.off()
        time.sleep(0.01)
        self.pin_oledreset.on()
        time.sleep(0.01)
        cmds = [
                0x40,             # Set Display start line
                0xA0,             # Bottom View no segment remap
                0xC0,             # Bottom View COM scan direction normal
                0x2E,             # StartColumnAddress
                0x8D, 0x95,       # Switch Charge Pump (9V)
                0x20, 0x02,       # Set Memory AddressMode
                0x81, 0xFF,       # Set Brightness
                0xD5, 0x40,       # Set Display Clock Divide
                0xD9, 0xF1,       # Set Precharge Period
                0xAD, 0x30,       # Set Internal Ref
                0x21, 0x0D, 0x72, # Set ColumnAddress
                0x22, 0x00, 0x3F, # Set PageAddress
                0xAF,             # Display on
            ]
        for c in cmds:
            self.disp.write_cmd(c)

    def oled_blankimage(self):
        self.imagedraw.rectangle((0, 0, OLED_WIDTH, OLED_HEIGHT), outline=0, fill=0)

    def oled_show(self):
        self.disp.image(self.image)
        self.disp.show()

    def init_adc(self):
        try:
            self.adc_setup_bytes = bytes([
                      0x80 # setup
                    | 0x40 # internal reference, auto-shutdown reference, AIN3 is input
                    | 0x00 # unipolar, input range 0-Vref
                    | 0x01 # prevent reset
                           # the rest is 0, use internal clock, unipolar mode
                ])
            self.i2c.writeto(I2CADDR_ADC, self.adc_setup_bytes)
            self.adc_avail = True
        except:
            self.adc_avail = False

    def batt_read(self):
        if self.adc_avail == False:
            return [-1, -1], [-1, -1], [-1, -1]
        self.i2c.writeto(I2CADDR_ADC, bytes([self.adc_setup_bytes[0], 0x01 + (0x01 << 1)])) # read up to chan 1, single ended
        result = bytearray(2)
        self.i2c.readfrom_into(I2CADDR_ADC, result)
        self.batt_raw[0] = result[0]
        self.batt_raw[1] = result[1]

        self.batt_volt[0] = adc_to_voltage(self.batt_raw[0])
        self.batt_volt[1] = adc_to_voltage(self.batt_raw[1])
        self.batt_chg [0] = voltage_to_charge(self.batt_volt[0])
        self.batt_chg [1] = voltage_to_charge(self.batt_volt[1])

        return self.batt_raw, self.batt_volt, self.batt_chg

    def buzzer_on(self):
        self.buzzer_is_on = time.monotonic()
        self.buzzer.on()

    def buzzer_off(self):
        self.buzzer_is_on = 0
        self.buzzer.off()

    def on_pressed_1(self):
        self.button_queue.put(1)
    def on_pressed_2(self):
        self.button_queue.put(2)
    def on_pressed_3(self):
        self.button_queue.put(3)
    def on_pressed_4(self):
        self.button_queue.put(4)
    def on_pressed_5(self):
        self.button_queue.put(5)

    def pop_button(self):
        if self.button_queue.empty():
            return 0
        return self.button_queue.get()

    def is_btn_held(self, num):
        num -= 1
        return self.buttons[num].is_held or self.buttons[num].is_pressed or self.buttons[num].value != 0

    def cpu_highfreq(self):
        cpu_highfreq()

    def cpu_lowfreq(self):
        cpu_lowfreq()

class BucketIO_Simulator:
    def __init__(self):
        self.is_sim = True
        self.button_queue = queue.Queue()
        self.image = Image.new("1", (OLED_WIDTH + 2, OLED_HEIGHT + 2))
        self.imagedraw = ImageDraw.Draw(self.image)
        self.oled_blankimage()

    def hw_init(self):
        pass

    def oled_blankimage(self):
        self.imagedraw.rectangle((0, 0, OLED_WIDTH + 2, OLED_HEIGHT + 2), outline=0, fill=0)

    def oled_show(self):
        npimg = numpy.array(self.image.convert('RGB'))
        npimgx2 = cv2.resize(npimg, ((OLED_WIDTH + 2) * 3, (OLED_HEIGHT + 2) * 3), interpolation = cv2.INTER_NEAREST)
        cv2.imshow("bucket", npimgx2)
        k = cv2.waitKey(1)
        if k == ord('1'):
            self.button_queue.put(1)
        elif k == ord('2'):
            self.button_queue.put(2)
        elif k == ord('3'):
            self.button_queue.put(3)
        elif k == ord('4'):
            self.button_queue.put(4)
        elif k == ord('5'):
            self.button_queue.put(5)

    def batt_read(self):
        return [2048, 2048], [8.4, 8.4], [100, 100]

    def pop_button(self):
        if self.button_queue.empty():
            return 0
        return self.button_queue.get()

    def is_btn_held(self, num):
        return False

    def buzzer_on(self):
        pass

    def buzzer_off(self):
        pass

    def cpu_highfreq(self):
        pass

    def cpu_lowfreq(self):
        pass

def adc_to_voltage(x):
    if x < 0:
        return 0
    vbefore = x * BATT_ADC_INTERNAL_REF / (pow(2, 8) - 1)
    vafter = vbefore * (BATT_VDIV_RLOWER + BATT_VDIV_RUPPER) / BATT_VDIV_RLOWER

    vafter *= BATT_VOLT_CALIBRATION_SCALE_M
    vafter += BATT_VOLT_CALIBRATION_SCALE_B
    # 8.0 = 5.96 * m + b
    # 6.0 = 5.22 * m + b

    vafter += BATT_VOLT_COMPENSATE
    return vafter if vafter > 0 else 0

def voltage_to_charge(x):
    x = x / 2 # per cell voltage
    tbl = [   # lookup table for voltage vs charge state
            [4.17 , 100],
            [4.0  , 85],
            [3.4  , 10],
            [3.15 , 0],
            [2.8  , -1],
            [0    , -1],
        ]
    last = None

    if x >= tbl[0][0]: # full battery
        return 100

    # do an interpolation between table entries
    for t in tbl:
        if x >= t[0]:
            return (((x - t[0]) * (last[1] - t[1])) / (last[0] - t[0])) + t[1]
        last = t

    return -100 # past last table element

def run_cmdline_read(x):
    s = ""
    with os.popen(x) as p:
        s = p.read()
    if "is not recognized as an internal or external command" in s:
        raise Exception("ERROR: command \"%\" does not exist" % x)
    return s

def has_rtc():
    global is_embedded
    if is_embedded == False:
        return False
    x = os.system("hwclock -rv >/dev/null")
    if x == 0:
        print("HW clock detected")
        return True
    x = run_cmdline_read("hwclock -rv")
    x = str(x).lower()
    if "using the rtc interface to the clock" in x:
        print("HW clock detected")
        return True
    if "no usable clock" in x or "cannot access the hardware clock" in x or "Cannot access the Hardware Clock".lower() in x:
        return False
    return False

def cpu_userspace():
    g = glob.glob("/sys/devices/system/cpu/cpu*/cpufreq/scaling_governor", recursive=True)
    for cpu in g:
        os.system("sudo sh -c \"echo userspace > %s\"" % cpu)

def cpu_get_maxminfreq(word):
    if os.name == "nt":
        return 0
    maxfreq = 0
    minfreq = 999999999999
    g = glob.glob("/sys/devices/system/cpu/cpu*/cpufreq/cpuinfo_" + word + "_freq", recursive=True)
    for cpu in g:
        s = run_cmdline_read("cat " + cpu)
        s = s.strip() if s is not None else ""
        if s.isnumeric():
            x = int(s)
            if x > maxfreq:
                maxfreq = x
            if x < minfreq:
                minfreq = x
    if word == "max":
        return maxfreq
    else:
        return minfreq

CPU_MAXFREQ = cpu_get_maxminfreq("max")
CPU_MINFREQ = cpu_get_maxminfreq("min")

def cpu_highfreq(freq_hz = CPU_MAXFREQ):
    g = glob.glob("/sys/devices/system/cpu/cpu*/cpufreq/scaling_setspeed", recursive=True)
    for cpu in g:
        os.system("sudo sh -c \"echo %d > %s\"" % (freq_hz, cpu))

def cpu_lowfreq(freq_hz = CPU_MINFREQ):
    g = glob.glob("/sys/devices/system/cpu/cpu*/cpufreq/scaling_setspeed", recursive=True)
    for cpu in g:
        os.system("sudo sh -c \"echo %d > %s\"" % (freq_hz, cpu))

def test_adc():
    bhw = BucketIO()
    bhw.init_pins()
    bhw.init_adc()
    print("Bucket IO initialized ADC")
    while True:
        raws, volts, percentages = bhw.batt_read()
        print("%d, %5d, %.2f, %.1f, %5d, %.2f, %.1f" % (round(time.monotonic()), raws[0], volts[0], percentages[0], raws[1], volts[1], percentages[1]))
        time.sleep(1)

def test_buttons():
    bhw = BucketIO()
    bhw.init_buttons()
    print("Bucket IO initialized buttons")
    while True:
        time.sleep(1)
        s = "%d, " % (round(time.monotonic()))
        if bhw.button_queue.empty():
            s += "none"
        while bhw.button_queue.empty() == False:
            s += "%d, " % bhw.button_queue.get()
        print(s)

def test_buzzer():
    bhw = BucketIO()
    bhw.init_pins()
    print("Bucket IO initialized buzzer")
    while True:
        time.sleep(1)
        bhw.buzzer_on()
        print("%d - buzz" % (round(time.monotonic())))
        time.sleep(0.2)
        bhw.buzzer_off()

def test_oled(t = 0):
    bhw = BucketIO()
    bhw.init_pins()
    bhw.init_oled()
    font = ImageFont.truetype("04b03mod.ttf", size = 8)
    (font_width, font_height) = font.getsize("X")
    while True:
        bhw.oled_blankimage()
        s = "Time: %.3f" % time.monotonic()
        bhw.imagedraw.text((2, 2), s, font=font, fill=255)
        bhw.oled_show()
        print(s)
        time.sleep(t) # this manages about 10 FPS

if __name__ == "__main__":
    if len(sys.argv) > 1:
        if sys.argv[1] == "adc":
            test_adc()
        elif sys.argv[1] == "oled":
            test_oled()
        elif sys.argv[1] == "buzzer":
            test_buzzer()
        elif sys.argv[1] == "buttons":
            test_buttons()
        elif sys.argv[1] == "cpu":
            cpu_userspace()
            print("CPU frequencies range: %d - %d" % (CPU_MINFREQ, CPU_MAXFREQ))
        elif sys.argv[1] == "cpu_high":
            cpu_userspace()
            print("CPU frequencies range: %d - %d" % (CPU_MINFREQ, CPU_MAXFREQ))
            cpu_highfreq()
        elif sys.argv[1] == "cpu_low":
            cpu_userspace()
            print("CPU frequencies range: %d - %d" % (CPU_MINFREQ, CPU_MAXFREQ))
            cpu_lowfreq()
    else:
        bhw = BucketIO() # make an instance for running in terminal

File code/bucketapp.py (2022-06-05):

#!/usr/bin/env python3

import os, sys, time, datetime, shutil, subprocess, signal, random, math, glob
import threading, queue, socket
import psutil

from PIL import Image, ImageDraw, ImageFont, ExifTags
import pyftpdlib.log

bucket_app = None

CONFIG_FILE_NAME    = "bucket_cfg.json"
LOW_SPACE_THRESH_MB = 200
LOW_BATT_THRESH     = 10

ALARMFLAG_DISKFULL   = 1
ALARMFLAG_LOSTFILE   = 2
ALARMFLAG_BATTLOW    = 4
ALARMFLAG_COPYERR    = 8

CLONING_OFF        = 0
CLONING_MAIN2REDUN = 1
CLONING_BOTH       = 2
CLONING_REDUN2MAIN = 3
CLONING_DONE       = -1

UX_LINESPACE = 0

UXSCREEN_MAIN = 0
UXSCREEN_MENU = 1

import bucketio, bucketmenu, bucketftp, bucketviewer, bucketcopy, bucketlogger, bucketutils

logger = bucketlogger.getLogger()

class BucketApp:
    def __init__(self, hwio = None):
        self.disks = []
        self.cfg = None
        self.ftp_server  = None
        self.ftp_thread  = None
        self.http_server = None
        self.http_thread = None
        self.hwio = hwio
        self.has_rtc = bucketio.has_rtc()
        self.has_date = None
        self.copier = bucketcopy.BucketCopier(self)
        self.last_file = None
        self.last_file_date = None
        self.start_monotonic_time = time.monotonic()
        self.session_last_act     = None
        self.session_last_nonact  = None
        self.session_last_5       = []
        self.alarm_reason = 0
        self.batt_lowest  = 100
        self.cpu_freq_high = False
        self.reset_stats()

        self.font = ImageFont.truetype("04b03mod.ttf", size = 8)
        self.font_has_lower = True
        self.last_frame_time = 0
        self.ux_frame_cnt    = 0
        self.ux_screen       = UXSCREEN_MAIN
        self.ux_menu         = bucketmenu.BucketMenu(self)

        self.thumbnail_queue = queue.Queue()
        self.ftmgr = bucketviewer.BucketWebFeatureManager()

    def reset_stats(self):
        self.session_first_number = None
        self.session_last_number  = None
        self.session_total_cnt    = 0
        self.session_lost_cnt     = 0
        self.session_lost_list    = []
        self.both_file_types      = 0
        self.fsize_idx            = 0
        self.fsize_list           = [0] * 6
        self.fsize_avg            = 80 # start with a worse case estimate

    def reset_lost(self):
        self.session_lost_cnt     = 0
        self.session_lost_list    = []

    def reset_alarm(self):
        self.alarm_reason = 0
        self.hwio.buzzer_off()

    def update_disk_list(self):
        partitions = bucketutils.get_mounted_disks()
        if len(self.disks) <= 0:
            # on boot, go from no disks to having many disks
            # use the biggest disk as primary write target
            partitions.sort(reverse = True, key = disk_sort_func)
            for i in partitions:
                self.disks.append(i)
            bucketlogger.reconfig(bapp = self)
        else:
            # update the list in a way that preserves the previous order
            # this way, the top disk in the list is still the primary write target
            newlist = []
            for i in self.disks:
                found = False
                for j in partitions:
                    if i == j:
                        found = True
                        break
                if found:
                    newlist.append(i)
            found = False
            for i in partitions:
                found = False
                for j in newlist:
                    if i == j:
                        found = True
                        break
                if not found:
                    newlist.append(i)
            self.disks = newlist
            if not found:
                bucketlogger.reconfig(bapp = self)

    def get_root(self):
        self.update_disk_list()
        if len(self.disks) > 0:
            return self.disks[0]
        return None

    def still_has_space(self):
        if len(self.disks) <= 0:
            return False
        total, free = bucketutils.get_disk_stats(self.disks[0])
        if free < LOW_SPACE_THRESH_MB:
            # another disk available?
            while i < len(self.disks):
                total2, free2 = bucketutils.get_disk_stats(self.disks[i])
                if free2 >= LOW_SPACE_THRESH_MB: # free space on another disk?
                    disk0 = self.disks[i]
                    self.disks[i] = self.disks[0]
                    self.disk[0] = disk0
                    return True
                i += 1
            return False
        else:
            return True

    def get_datetime(self):
        if self.has_rtc or self.has_date is None:
            return datetime.datetime.now()
        elif self.has_date is None and self.last_file_date is not None:
            return self.last_file_date + datetime.timedelta(seconds = self.get_elapsed_secs())
        elif self.has_date is not None:
            return self.has_date + datetime.timedelta(seconds = self.get_elapsed_secs())

    def get_date_str(self):
        return self.get_datetime().strftime("%y%m%d")

    def get_elapsed_secs(self):
        return time.monotonic() - self.start_monotonic_time

    def on_activity(self):
        self.session_last_act = time.monotonic()

    def on_nonactivity(self):
        self.session_last_nonact = time.monotonic()

    def cpu_highfreq(self):
        if self.cpu_freq_high == True:
            return
        self.cpu_freq_high = True
        self.hwio.cpu_highfreq()

    def cpu_lowfreq(self):
        if self.cpu_freq_high == False:
            return
        self.cpu_freq_high = False
        self.hwio.cpu_lowfreq()

    def cpu_choosefreq(self):
        busy = False
        if self.session_last_act is not None and (time.monotonic() - self.session_last_act) < 2:
            busy = True
        elif self.copier.is_busy() or self.ftmgr.thumbgen_is_busy():
            busy = True
        if busy == False:
            self.cpu_lowfreq()
        # all the other threads will automatically call cpu_highfreq
        # elif busy == True:
        #     self.cpu_highfreq()

    def load_cfg(self):
        import json

        # find all disks that may contain a config file
        disks = bucketutils.get_mounted_disks()
        disks.sort(reverse = True, key = disk_sort_func)
        if len(disks) <= 0:
            print("no disks to load config from")
            return

        # look on all disks for the config file
        for d in disks:
            path = os.path.join(d, CONFIG_FILE_NAME)
            if os.path.isfile(path):
                try:
                    print("trying to load json config from " + path)
                    with open(path, 'r') as f:
                        self.cfg = json.load(f) # loads a file as a dictionary
                    return
                except Exception as ex:
                    logger.error("Failed to load JSON cfg file at \"" + path + "\", exception: " + str(ex))
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

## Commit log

2022-05-06 parts for circuit, day 1
    [bucket.brd, bucket.sch]
2022-05-07 major progress on circuit design
    [bucket.brd, bucket.sch]
2022-05-08 circuit first rev finished and gerbers sent to manufacture
    [bucket.brd, bucket.sch]
2022-05-08 circuit schematic as image
2022-05-16 started mech design of 3D printed case
    [assem.SLDASM, bucket_hat.SLDPRT, pi_box.SLDPRT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]
2022-05-17 mech updates, corrected for standoff height and screw size
    [assem.SLDASM, pi_box.SLDPRT]
2022-05-17 tested bucketio on real hardware
    ADC definitely not reading right, needs calibration, also can't detect removed battery
    OLED working
    Buttons working but can't trust the "held" function
    Buzzer not making a sound
    [bucketio.py]
2022-05-18 mech changes to 3D printed box, added holes for LEDs, etc
    [assem.SLDASM, pi_box.SLDPRT]
2022-05-18 adc calibration
2022-05-22 code syntax fixes before running in simulation
    [bucketapp.py, bucketcopy.py, bucketftp.py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]
2022-05-24 code FTP working, fixed memory leaks, fixed lost file miscounting
    [bucketapp.py, bucketcopy.py, bucketftp.py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]
2022-05-25 code fixed a bunch of linux-only bugs
    [bucketapp.py, bucketcopy.py, bucketftp.py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]
2022-05-25 slightly more sane fix for failed path joining
    [bucketapp.py]
2022-05-25 code more fixes for bugs found on pi
    [bucketapp.py, bucketftp.py, bucketio.py]
2022-05-30 mech changes, printed and assembled
    [assem.SLDASM, pi_box.SLDPRT, pi_box_bottom.STL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]
2022-05-30 documentation photographs
    [assem.SLDASM]
2022-06-05 added buttons to mass delete
2024-06-27 PCB v2
    [bucket.brd, bucket.sch]
2024-06-27 new mech for new version
    [2.0_PIN_HEADER.SLDPRT, 2xUSB_2.0_PORT.SLDPRT, 2xUSB_3.0_PORT.SLDPRT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]
